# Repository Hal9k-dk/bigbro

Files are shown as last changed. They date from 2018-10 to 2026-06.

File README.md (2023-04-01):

# BigBro

BigBro is the system used by Hal9K to control access to its different advanced
machines, with RFID based access control.

The system is designed to cut power to the machines if no valid key-card is present
or in the special case of a 3D printer, if no special key-card is present, 
and a print isn't ongoing.

The first version of BigBro was designed around the ESP8266, specifically the WEMOS D1 mini.
Version 2 uses ESP32 with the [EspressIf ESP-IDF](https://idf.espressif.com/).

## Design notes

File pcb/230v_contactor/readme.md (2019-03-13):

# Contactor PCB
PCB design for the normal big-bro access boxes, meant to control a 230v contactor.

Eagle version 7.2.0

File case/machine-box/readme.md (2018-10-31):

## Case for the power-monitoring PCB

The source files for the case are [here](https://cad.onshape.com/documents/f34608c3b50537d27d2a70f4/w/dc4bf4f182cd748e33a69883/e/08b9ab1bdb92c4a2750b073b).

It's made on OnShape. To do anything but view you'll need a free account. For that reason step and stl files for the case have been provided here as well, in a folder of their own.

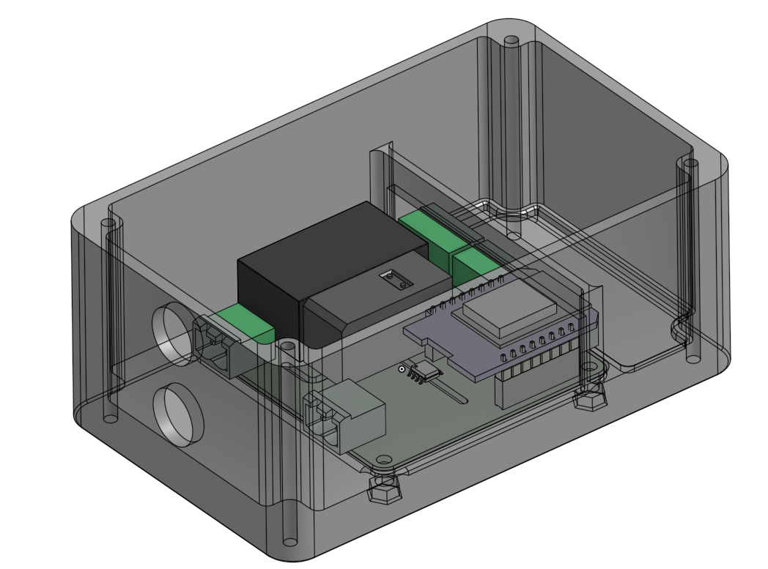
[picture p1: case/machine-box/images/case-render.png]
Case Render


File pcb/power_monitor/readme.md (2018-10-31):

# Power monitoring acces system

A module based on AndersV209s work on the Wemos D1 Mini based boards.
Main changes are:

- DPST relay that breaks both Live and Neutral and handles 8A
- ACS723 10A current monitoring chip

The changes have been done to support use on 3D printers, or other machines where the user won't be expected to leave their key FOB in the device, and where the board can then determine end of use when power draw drops significantly 

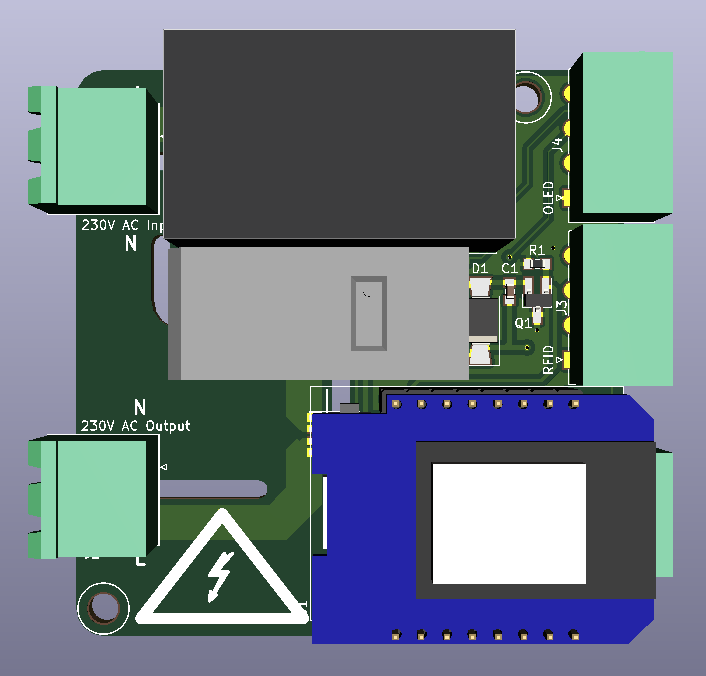
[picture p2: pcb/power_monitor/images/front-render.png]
Front-Render

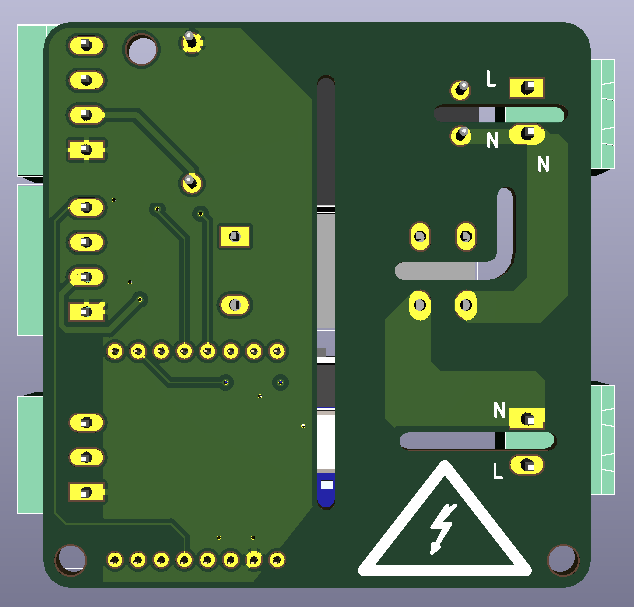
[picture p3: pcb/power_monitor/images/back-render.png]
Back-Render


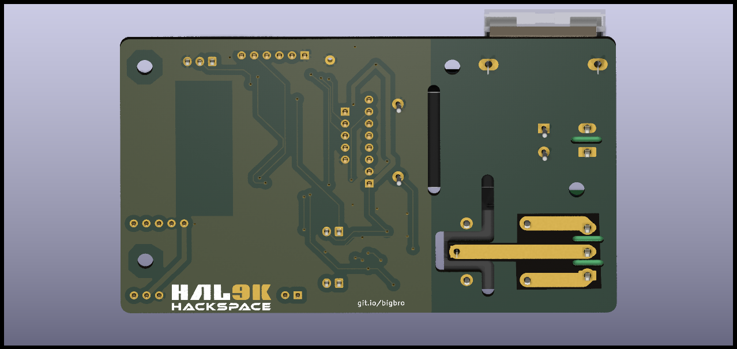
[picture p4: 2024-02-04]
pcb/bigbro_box_back.png

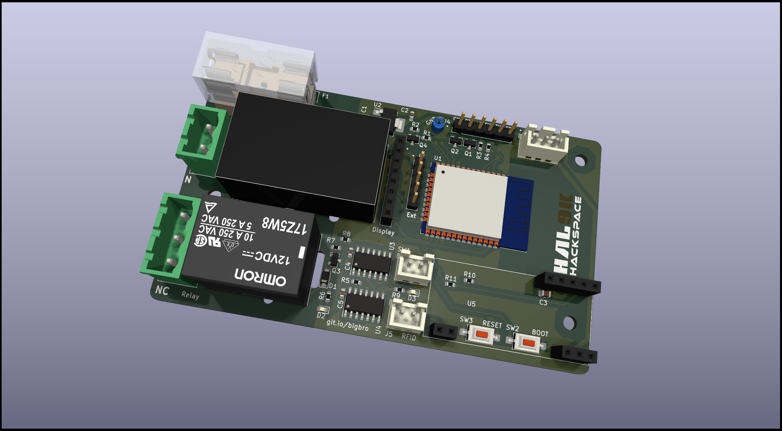
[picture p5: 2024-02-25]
pcb/bigbro_box.png

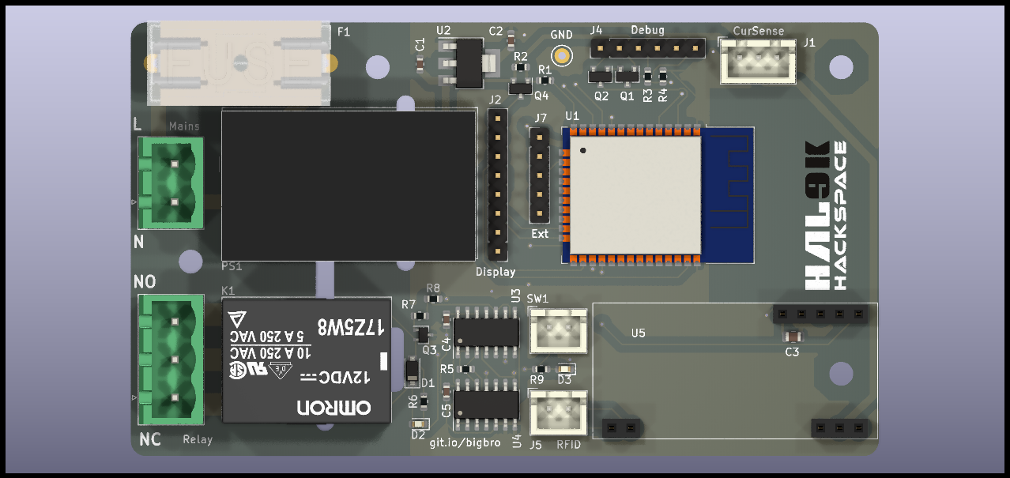
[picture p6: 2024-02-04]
pcb/bigbro_box_front.png

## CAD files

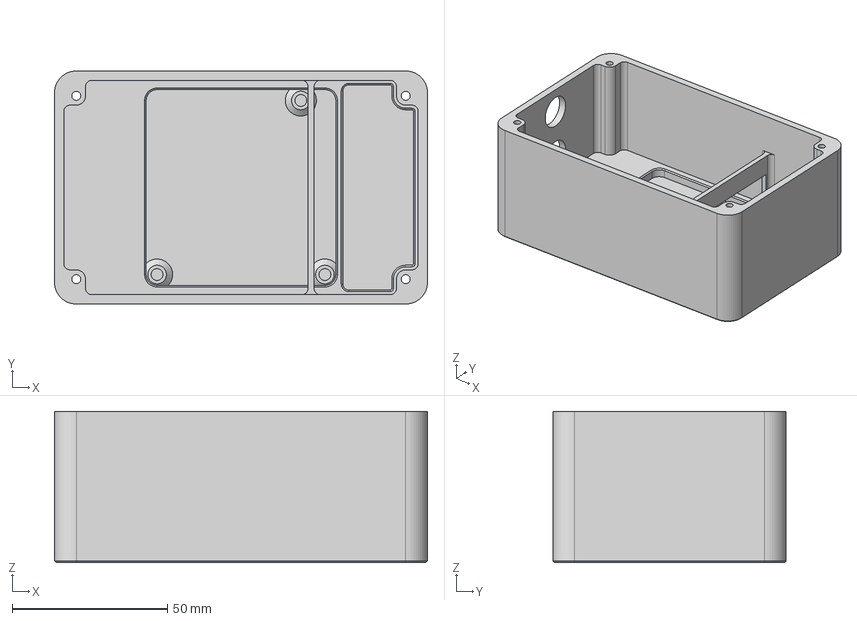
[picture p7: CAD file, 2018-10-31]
case/machine-box/step/Power monitor - Case.step
120.0 x 75.0 x 48.6 mm

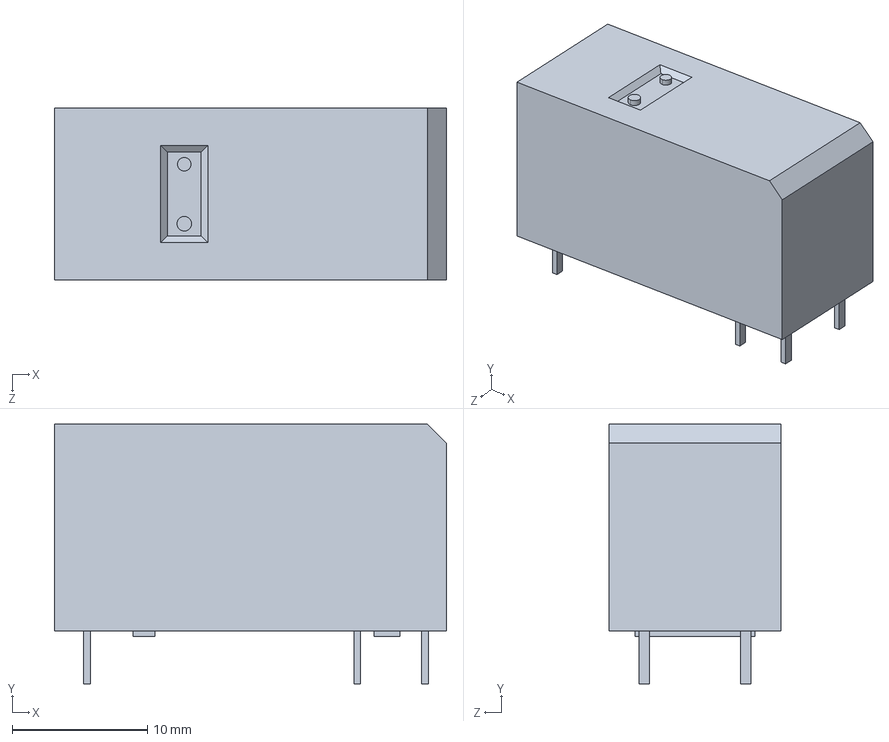
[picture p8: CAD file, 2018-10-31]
pcb/power_monitor/3Dmodels/G2RL_2A.step
29.0 x 19.2 x 12.7 mm

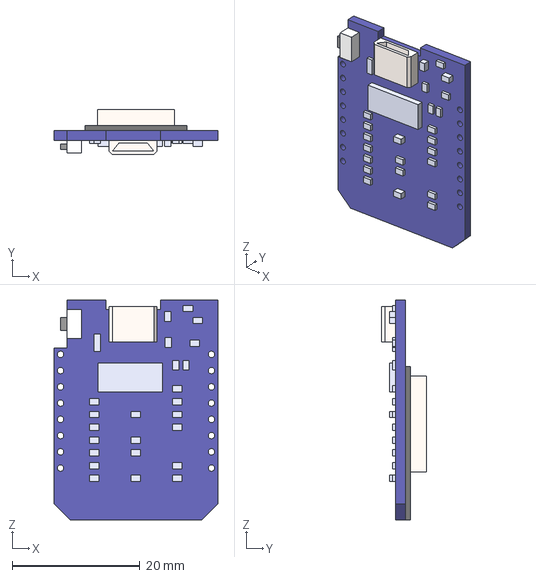
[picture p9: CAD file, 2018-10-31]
pcb/power_monitor/3Dmodels/WEMOSD1mini.step
25.6 x 7.00 x 34.4 mm

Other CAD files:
case/machine-box/stl/Power monitor - Case.stl

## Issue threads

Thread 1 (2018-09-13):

Class based branch(platformio) doesn't read softwareSerial

Duckle29, 2018-09-13:
For some odd reason, the software serial input from the RFID read always reads 0.

jenrik, 2018-09-14:
Both led in BaseController and the cardreader softwareserial uses pin 14

Duckle29, 2018-09-14:
Changed pin definition. The LED now works, so that's nice. This issue sadly isn't solved though :(

Duckle29, 2018-09-15:
Check bughunt branch to see the code

For some reason, interrupts don't fire in software serial, if the controller is of type ACS, derived from class base

Duckle29, 2018-09-16:
This is what the issue looks like in the bughunt branch
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

The problem is different here. In this case it's no interrupts at all. I have verified that the "attachInterrupt" function is called in softwareserial, so it does try to attach an interrupt, but it doesn't take effect.

jenrik, 2018-09-20:
I have tried adding a counter to SoftwareSerial that gets incremented in SoftwareSerial::rxRead(). It's getting incremented a lot which seems to indicate that interrupts are triggered. The problem now seem to be that interrupts are triggered all the time regardless of whether the rx pin has changed state, and that the it always receives 0 on the software serial.

Closed 2018-09-22.

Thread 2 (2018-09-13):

Class based branch (platformIO) doesn't update OLED after boot-up

Duckle29, 2018-09-13:
It seems the OLED fails to update once the device is past its setup.

Duckle29, 2018-09-13:
In general, it just looks like shit stops working once we enter loop() Stuff that does work is:

- Anything serial menu related

Duckle29, 2018-09-17:
This doesn't seem to actually be a thing

Closed 2018-09-17.

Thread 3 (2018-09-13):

ESP hangs on software reboot

Duckle29, 2018-09-13:
Using Either ESP.reset() or ESP.restart() hangs the ESP, with periodic WDT resets, that still doesn't properly reset it.

However a power-cycle or a push of the reset button works as expected

larsch, 2018-09-19:
Perhaps: https://arduino-esp8266.readthedocs.io/en/2.4.2/faq/readme.html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

Duckle29, 2018-09-19:
Yep that's it

Closed 2018-09-19.

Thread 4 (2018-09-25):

OLED UI consistency

Duckle29, 2018-09-25:
The UI can currently be a bit messy, with current state appearing on different lines, and error messages causing empty lines with little info.

This needs to be reworked so that the user doesn't have any doubts about what's going on with the controller.

Additionally, we should consider removing the current readout, at least after initial testing of the box has been completed.

Duckle29, 2019-03-18:
Current readout removed, states on consistent lines. Errors should be shown

Suggestion was made to not show the machine name if we need a line for additional information, as the boxes are attached to the relevant machines

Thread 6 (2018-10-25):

Display shows last user who swiped their card, not the actual last user

bullestock, 2018-10-25:
Simply inserting a card erases any information about the last user who printed.

Probably better to get the info from the backend anyway,

Duckle29, 2018-10-27:
Is there an endpoint on the API to get the last user for the printer?

bullestock, 2018-10-27:
> Is there an endpoint on the API to get the last user for the printer?

But of course: https://github.com/bullestock/acs/blob/master/apidoc.md

Duckle29, 2019-03-14:
This has been implemented with EEPROM storage for now. Will open a new issue on moving this functionality server-side when I'm at a pc

Closed 2019-03-14.

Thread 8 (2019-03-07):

In case of watchdog resets, the box cycles power several times

Duckle29, 2019-03-07:
Suggested solution is to prevent the box from enabling the machine if a card is present at boot.

Duckle29, 2019-03-14:
Issue 8 has been merged into platformio. We suspect the PSUs are dieing after prolonged 24/7 on time

AndersV209, 2020-05-26:
the issue is not caused by a power issue, there have been added a hardware latch to keep machine unlocked even if the esp restarts

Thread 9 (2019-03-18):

Move "last user" memory to access server

Duckle29, 2019-03-18:
To continue what was started in [issue#6](https://github.com/Hal9k-dk/bigbro/issues/6)

Currently the last user to print is stored in EEPROM, and read back if a card isn't present, and the state is IDLE. We might want to move this functionality server side.

This issue is to discuss that.

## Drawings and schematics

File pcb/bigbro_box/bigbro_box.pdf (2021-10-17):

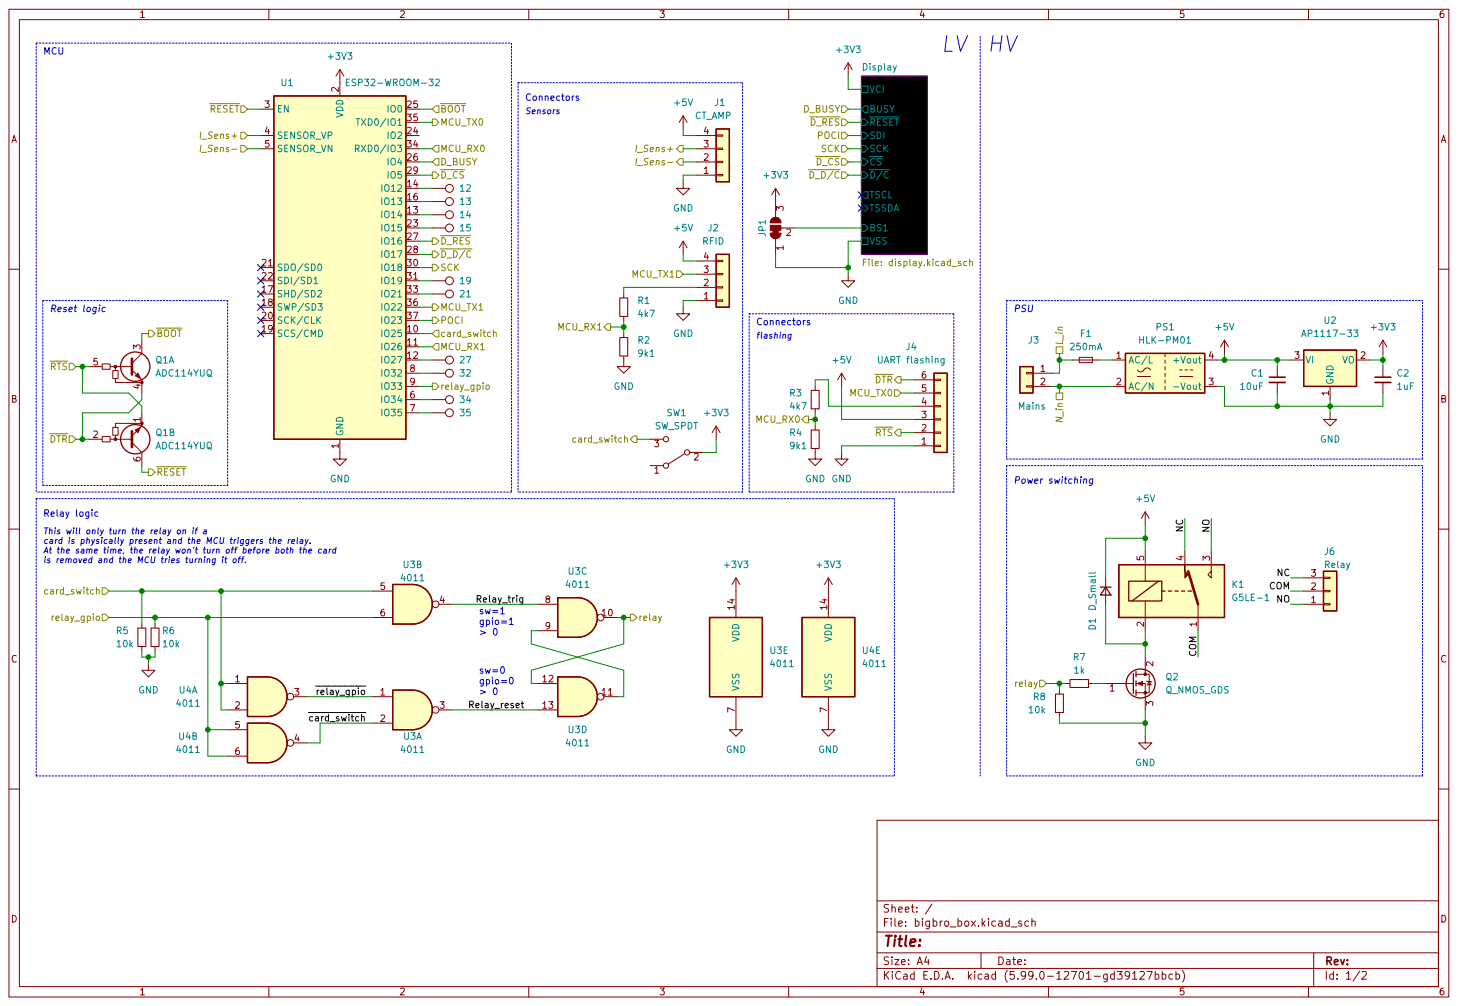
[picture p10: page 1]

TSCL BS1 VCI VSS Display

2 SCK/CLK 20 SDO/SD0 21 SDI/SD1 22

is removed and the MCU tries turning it off. Relay logic
This will only turn the relay on if a card is physically present and the MCU triggers the relay. At the same time, the relay won't turn off before both the card

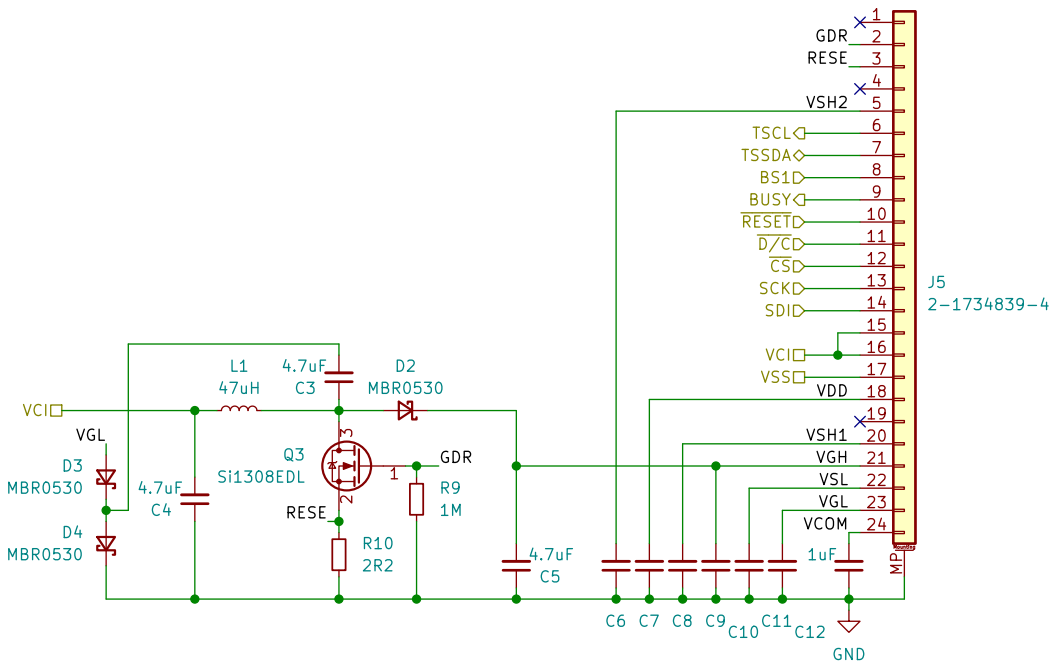
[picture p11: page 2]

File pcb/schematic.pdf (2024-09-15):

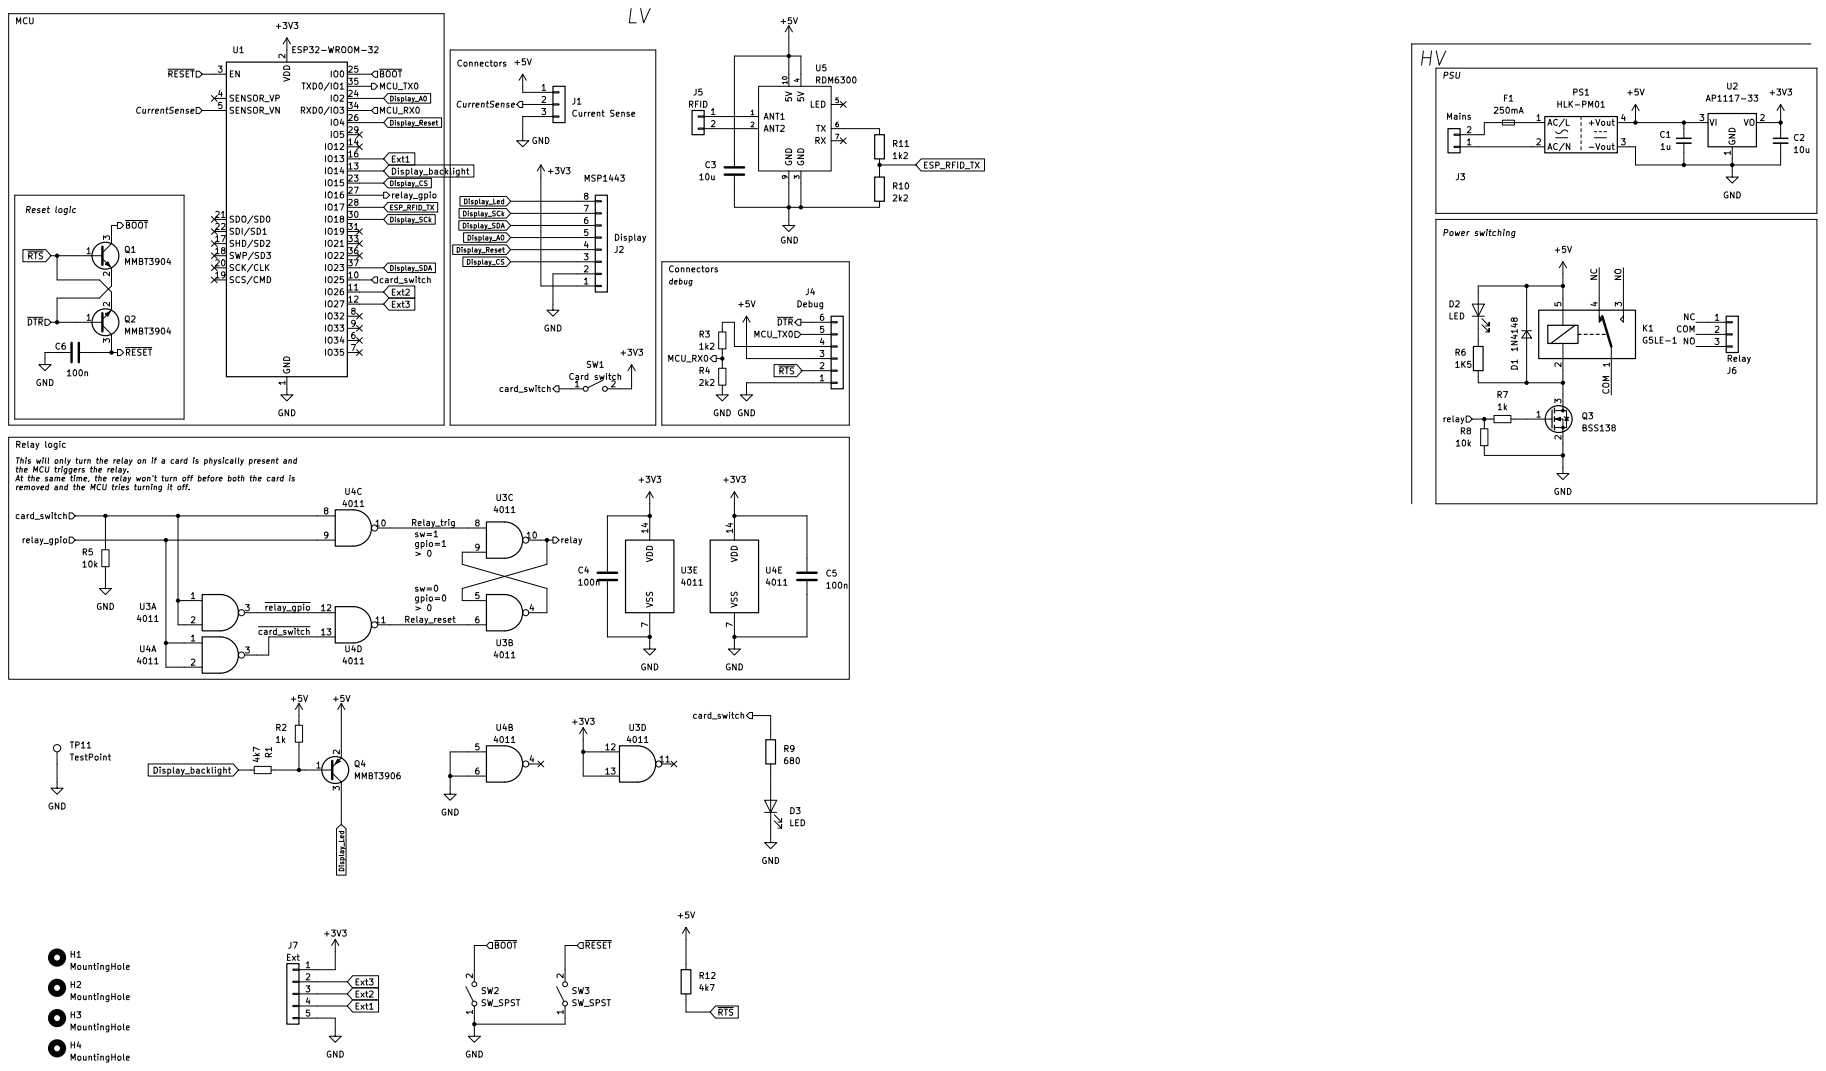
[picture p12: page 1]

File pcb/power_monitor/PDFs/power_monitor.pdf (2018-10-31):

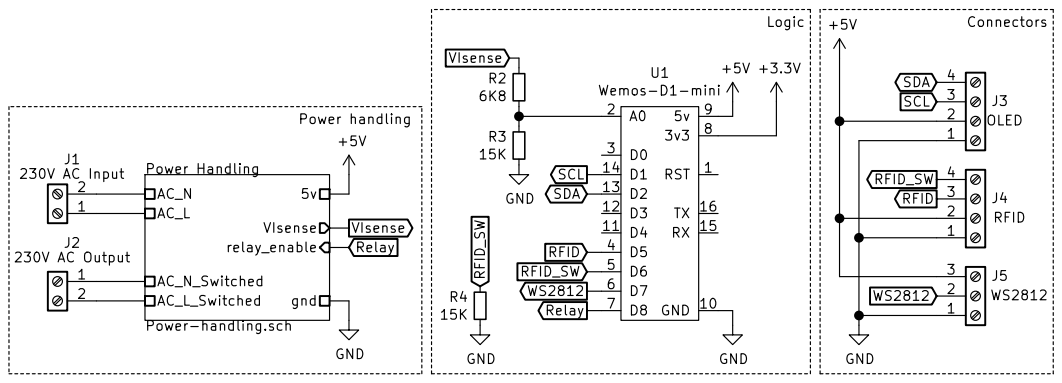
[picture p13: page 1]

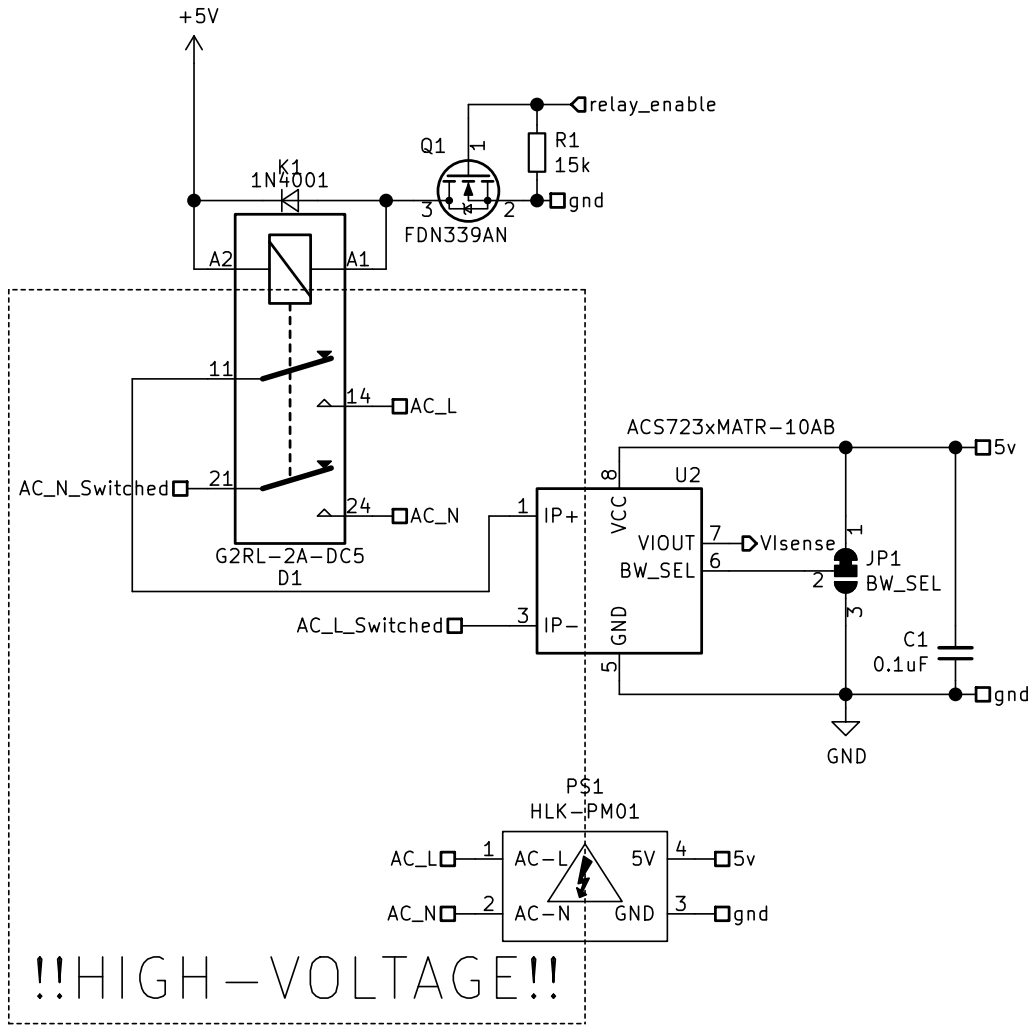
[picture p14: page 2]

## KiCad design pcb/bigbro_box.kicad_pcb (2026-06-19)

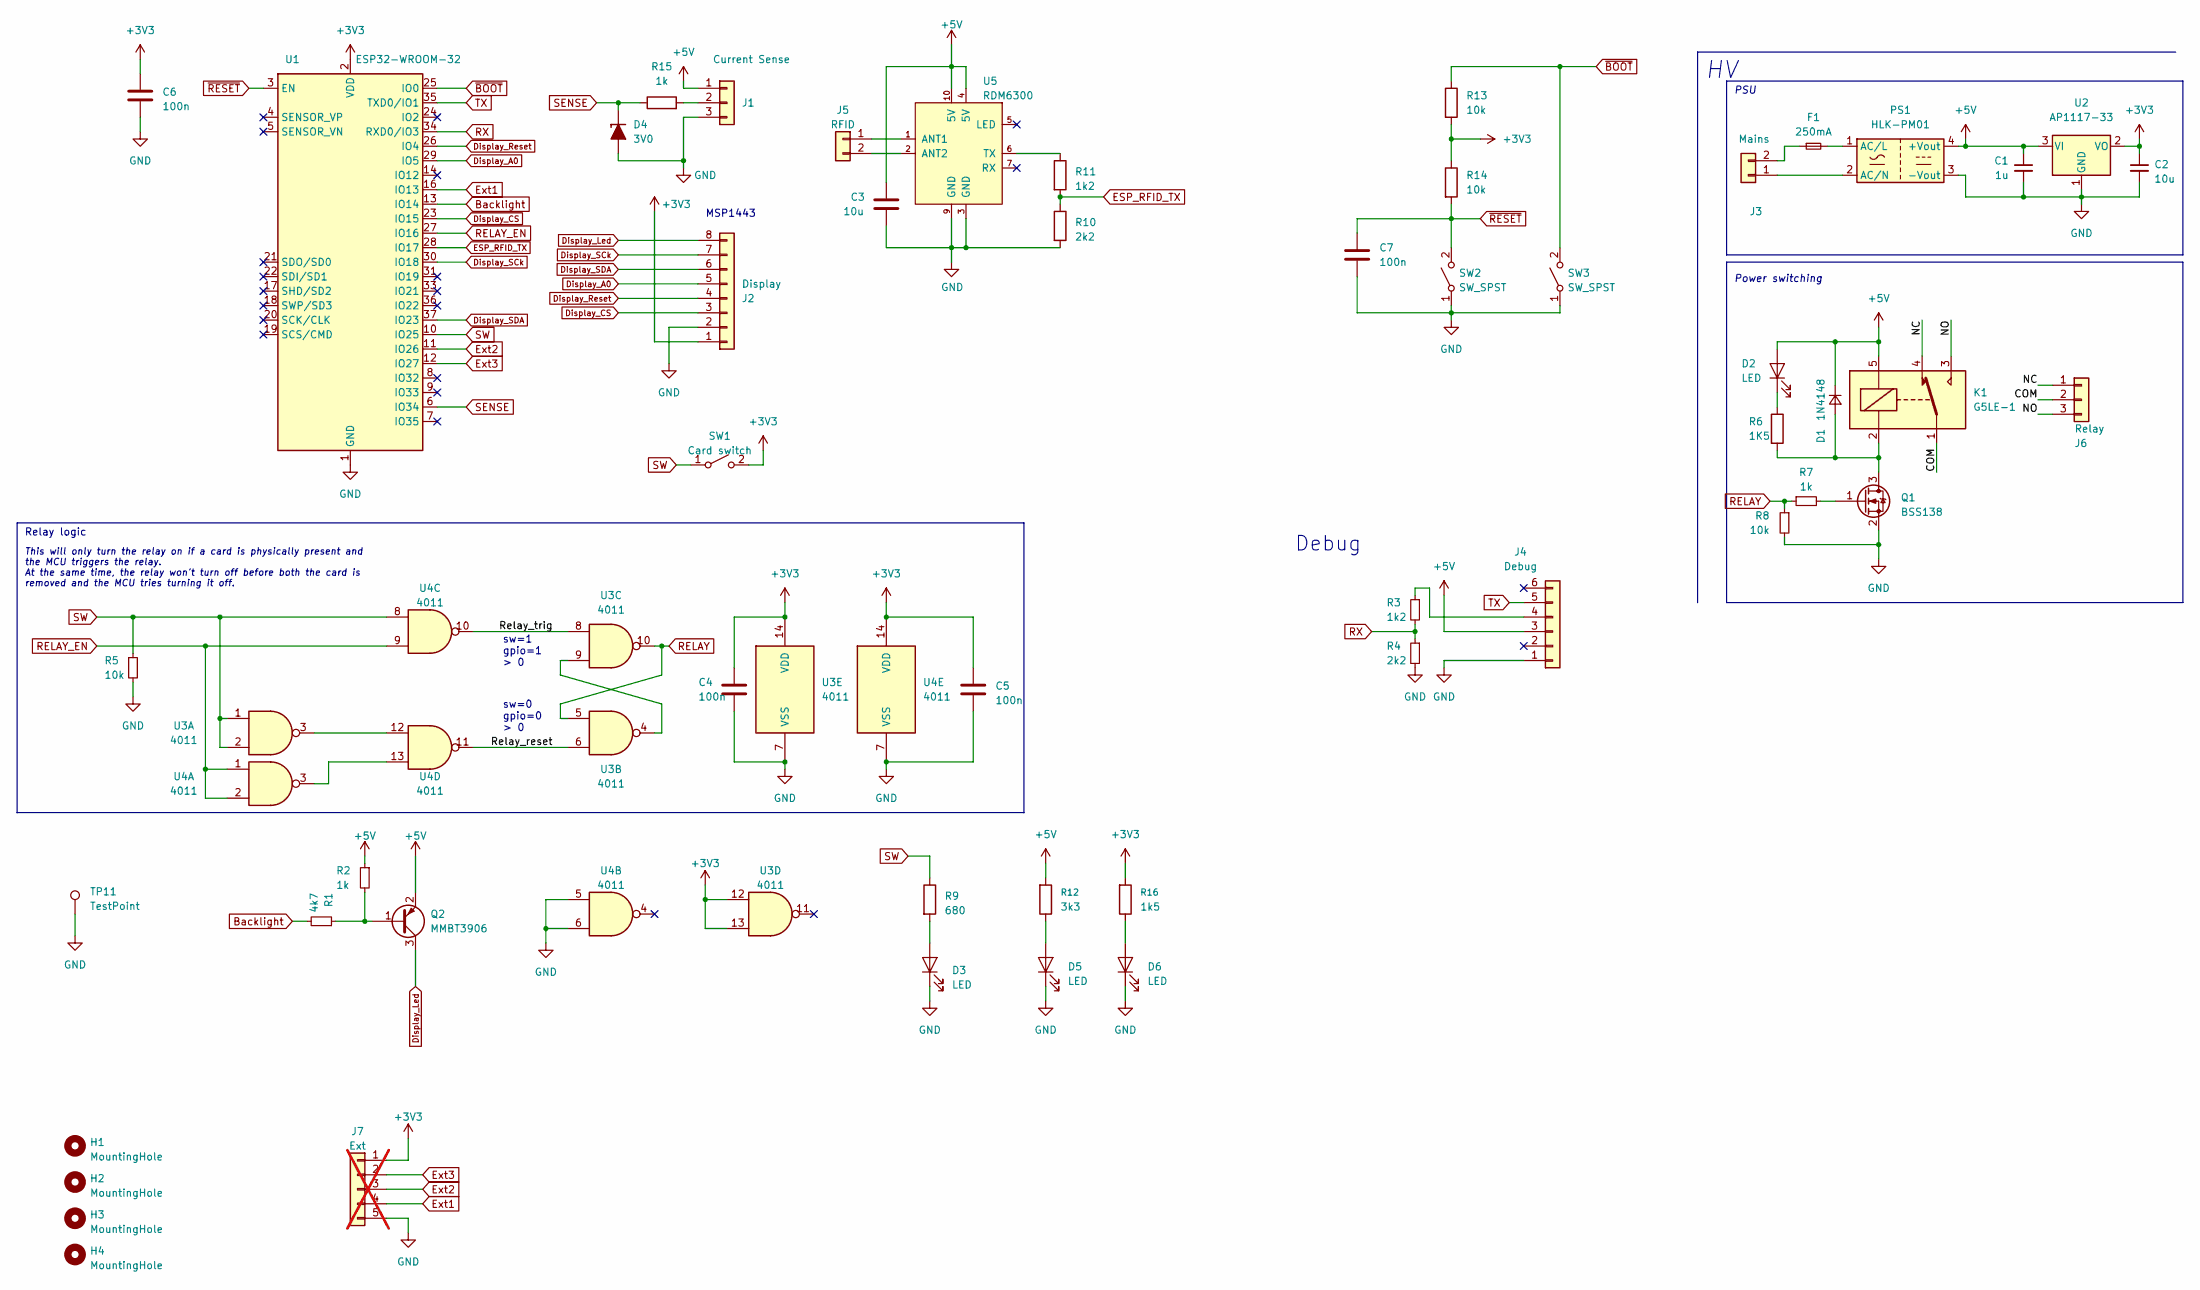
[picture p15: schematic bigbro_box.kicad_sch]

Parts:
C1: 1u; C_0603_1608Metric; LCSC C15849
C2: 10u; C_0603_1608Metric; LCSC C96446
C3: 10u; C_0603_1608Metric
C4, C5, C6: 100n; C_0603_1608Metric; LCSC C14663
C7: 100n; C_0603_1608Metric
D1: 1N4148; D_SOD-123
D2, D3, D5, D6: LED; LED_0603_1608Metric
D4: 3V0; D_MiniMELF
F1: 250mA; Fuse_Littelfuse_395Series
H1, H2, H3, H4: MountingHole; MountingHole_3.2mm_M3
J1: Current Sense; JST_XH_B3B-XH-A_1x03_P2.50mm_Vertical; LCSC C144394
J2: Display; PinSocket_1x08_P2.54mm_Vertical
J3: Mains; PhoenixContact_MSTBVA_2,5_2-G-5,08_1x02_P5.08mm_Vertical
J4: Debug; PinHeader_1x06_P2.54mm_Vertical; LCSC C37208
J5: RFID; JST_XH_B2B-XH-A_1x02_P2.50mm_Vertical
J6: Relay; PhoenixContact_MSTBVA_2,5_3-G-5,08_1x03_P5.08mm_Vertical
J7: Ext; PinHeader_1x05_P2.54mm_Vertical; not fitted
K1: G5LE-1; Relay_SPDT_Omron-G5LE-1
PS1: HLK-PM01; Converter_ACDC_HiLink_HLK-PMxx
Q1: BSS138; SOT-23
Q2: MMBT3906; SOT-23
R1: 4k7; R_0603_1608Metric; LCSC C23162
R2, R7: 1k; R_0603_1608Metric; LCSC C14676
R3: 1k2; R_0603_1608Metric; LCSC C22765
R4: 2k2; R_0603_1608Metric; LCSC C5362360
R5, R8: 10k; R_0603_1608Metric; LCSC C15401
R6: 1K5; R_0603_1608Metric; LCSC C22843
R9: 680; R_0603_1608Metric
R10: 2k2; R_0603_1608Metric
R11: 1k2; R_0603_1608Metric
R12: 3k3; R_0603_1608Metric
R13, R14: 10k; R_0603_1608Metric
R15: 1k; R_0603_1608Metric
R16: 1k5; R_0603_1608Metric
SW1: Card switch; JST_XH_B2B-XH-A_1x02_P2.50mm_Vertical
SW2, SW3: SW_SPST; SW_SPST_CK_RS282G05A3
TP11: TestPoint; TestPoint_Keystone_5000-5004_Miniature
U1: ESP32-WROOM-32; LCSC C95209
U2: AP1117-33; SOT-223-3_TabPin2
U3, U4: 4011; SOIC-14_3.9x8.7mm_P1.27mm
U5: RDM6300; RDM6300_B38.5x18.2mm

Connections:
+3V3: C2.1, C4.1, C5.1, C6.1, J2.1, J7.1, R13.2, R14.1, R16.1, SW1.2 (B), U1.2 (VDD), U2.2 (VO), U3.12, U3.13, U3.14 (VDD), U4.14 (VDD)
+5V: C1.1, C3.1, D1.1 (K), D2.2 (A), J1.1, J4.3, K1.5, PS1.4 (+Vout), Q2.2 (E), R2.1, R12.1, U2.3 (VI), U5.4 (5V), U5.10 (5V)
/COM: J6.2, K1.1
/NC: J6.1, K1.4
/NO: J6.3, K1.3
/Relay_reset: U3.6, U4.11
/Relay_trig: U3.8, U4.10
Backlight: R1.2, U1.13 (IO14)
Display_A0: J2.5, U1.29 (IO5)
Display_CS: J2.3, U1.23 (IO15)
Display_Led: J2.8, Q2.3 (C)
Display_Reset: J2.4, U1.26 (IO4)
Display_SCk: J2.7, U1.30 (IO18)
Display_SDA: J2.6, U1.37 (IO23)
ESP_RFID_TX: R10.1, R11.2, U1.28 (IO17)
Ext1: J7.4, U1.16 (IO13)
Ext2: J7.3, U1.11 (IO26)
Ext3: J7.2, U1.12 (IO27)
GND: C1.2, C2.2, C3.2, C4.2, C5.2, C6.2, C7.2, D3.1 (K), D4.2 (A), D5.1 (K), D6.1 (K), J1.3, J2.2, J4.1, J7.5, PS1.3 (-Vout), Q1.2 (S), R4.2, R5.2, R8.2, R10.2, SW2.1 (A), SW3.1 (A), TP11.1 (1_1), U1.1 (GND), U1.15 (GND), U1.38 (GND), U1.39 (GND), U2.1 (GND), U3.7 (VSS), U4.5, U4.6, U4.7 (VSS), U5.3 (GND), U5.9 (GND)
unnamed: D1.2 (A), K1.2, Q1.3 (D), R6.2
unnamed: D2.1 (K), R6.1
unnamed: D3.2 (A), R9.2
unnamed: D5.2 (A), R12.2
unnamed: D6.2 (A), R16.2
unnamed: J1.2, R15.2
unnamed: J3.1, PS1.2 (AC/N)
unnamed: F1.1, J3.2
unnamed: J4.4, R3.1
unnamed: J5.1, U5.1 (ANT1)
unnamed: J5.2, U5.2 (ANT2)
unnamed: F1.2, PS1.1 (AC/L)
unnamed: Q1.1 (G), R7.2
unnamed: Q2.1 (B), R1.1, R2.2
unnamed: U3.3, U4.12
unnamed: U3.4, U3.9
unnamed: U4.3, U4.13
unnamed: R11.1, U5.6 (TX)
RELAY: R7.1, R8.1, U3.5, U3.10
RELAY_EN: U1.27 (IO16), U4.1, U4.2, U4.9
RX: R3.2, R4.1, U1.34 (RXD0/IO3)
SENSE: D4.1 (K), R15.1, U1.6 (IO34)
SW: R5.1, R9.1, SW1.1 (A), U1.10 (IO25), U3.1, U3.2, U4.8
TX: J4.5, U1.35 (TXD0/IO1)
~BOOT: R13.1, SW3.2 (B), U1.25 (IO0)
~RESET: C7.1, R14.2, SW2.2 (B), U1.3 (EN)

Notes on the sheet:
Power switching
Relay logic
sw=1 gpio=1 > 0
This will only turn the relay on if a card is physically present and the MCU triggers the relay. At the same time, the relay won't turn off before both the card is removed and the MCU tries turning it off.
Debug
sw=0 gpio=0 > 0
MSP1443
PSU

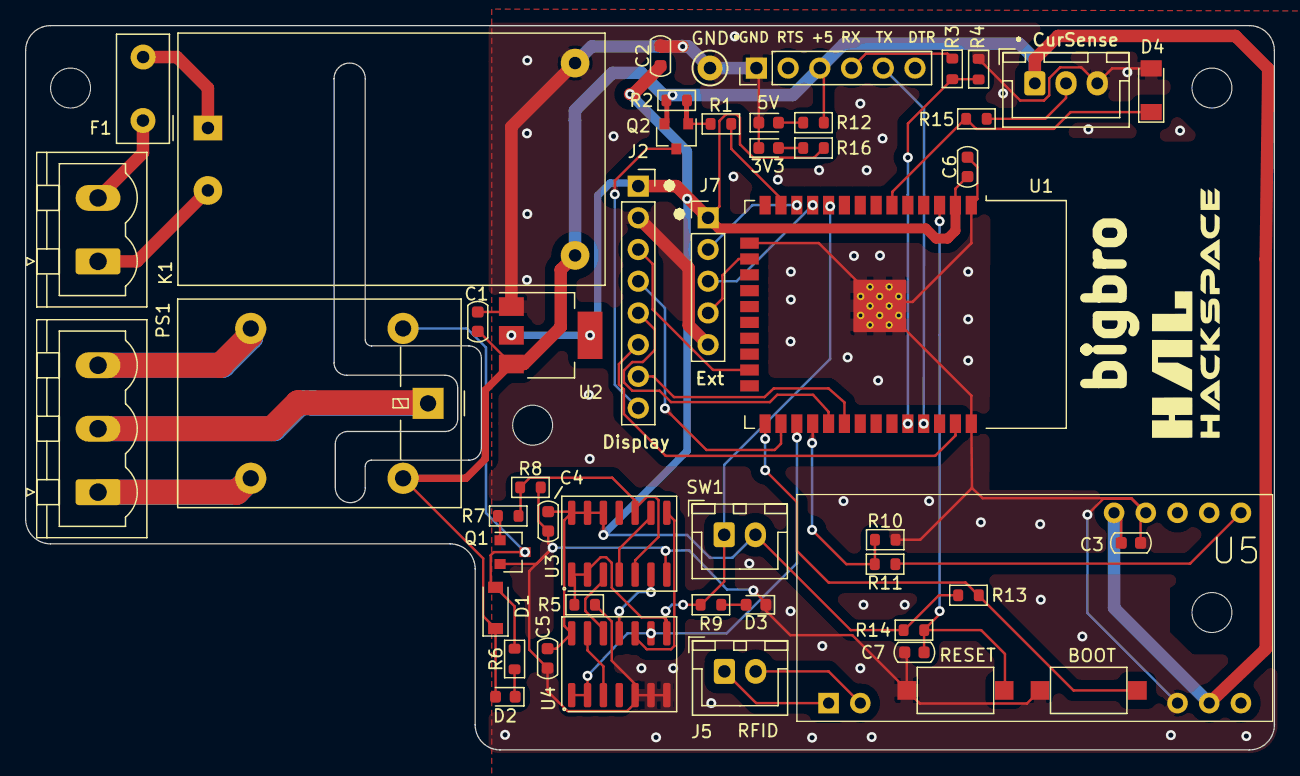
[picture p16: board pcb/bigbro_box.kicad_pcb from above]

Board: 2 copper layers, 100.0 x 58.0 mm, 54 parts (0 on the bottom side), 45 nets.

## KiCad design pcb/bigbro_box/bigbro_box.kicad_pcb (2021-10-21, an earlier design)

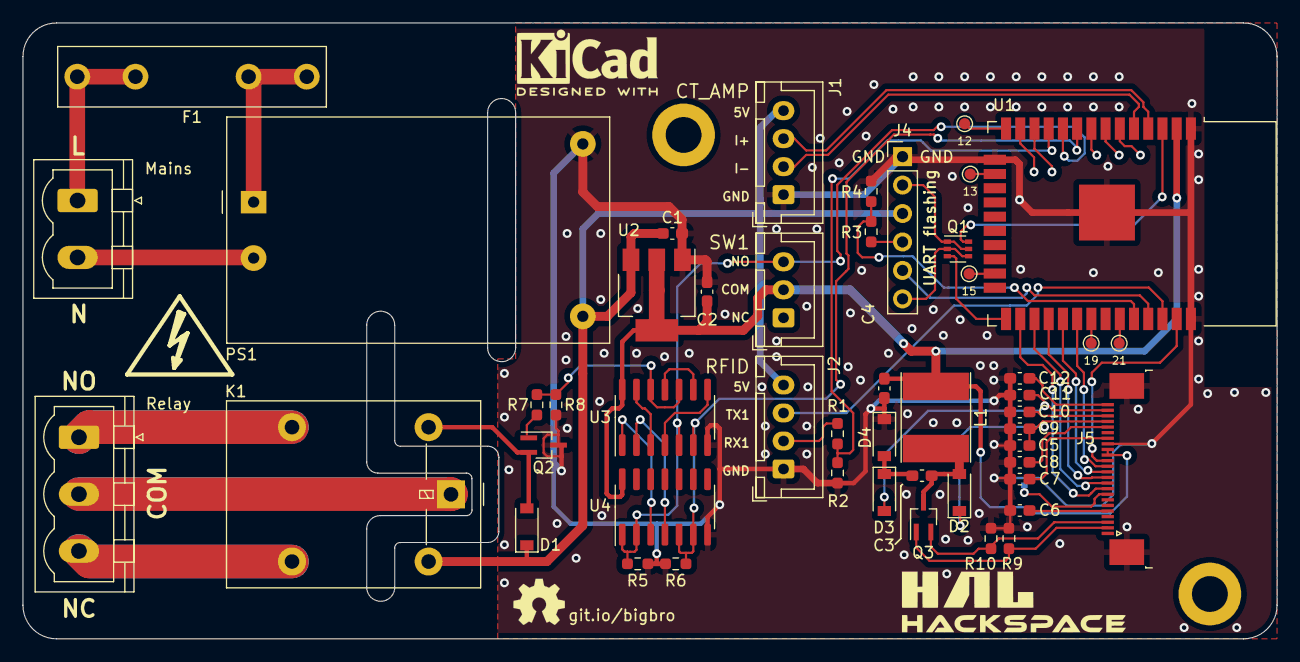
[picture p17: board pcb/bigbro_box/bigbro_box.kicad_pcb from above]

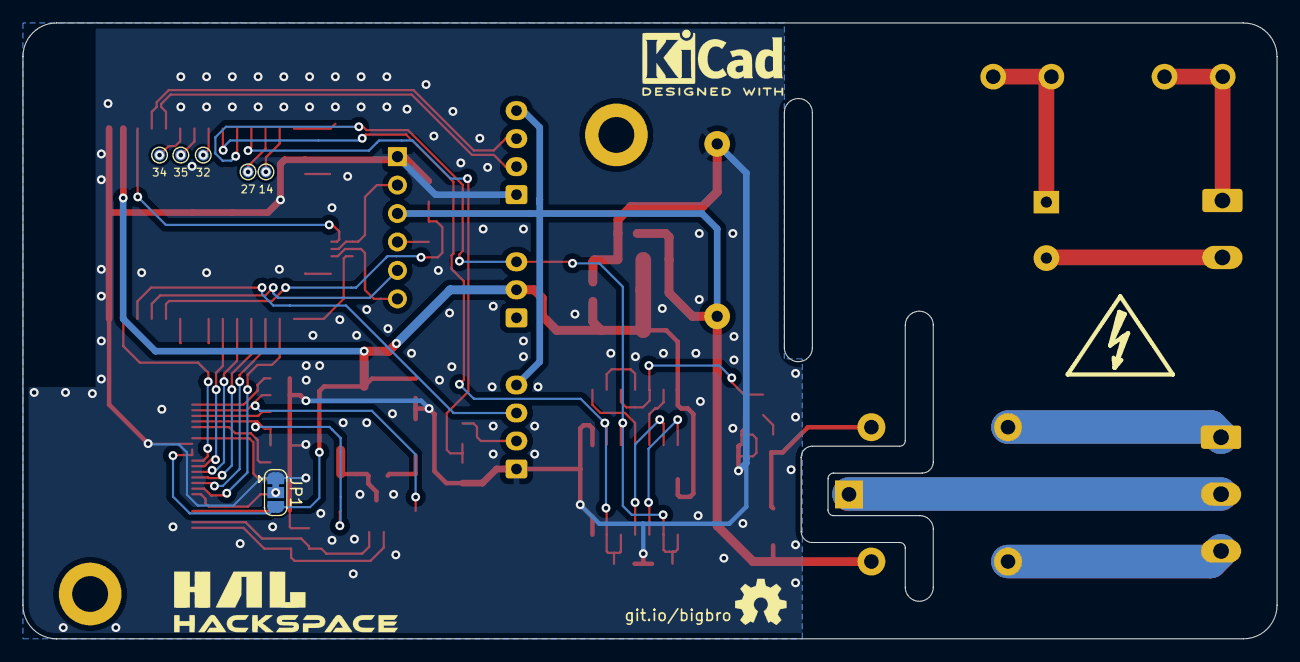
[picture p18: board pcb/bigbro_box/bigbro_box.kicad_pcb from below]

Board: 2 copper layers, 112.0 x 55.0 mm, 55 parts (6 on the bottom side), 59 nets.

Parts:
C1, C6, C7, C8, C9, C10, C11, C12: 1uF; C_0603_1608Metric_Pad1.08x0.95mm_HandSolder
C2: 10uF; C_0603_1608Metric_Pad1.08x0.95mm_HandSolder
C3, C4, C5: 4.7uF; C_0603_1608Metric_Pad1.08x0.95mm_HandSolder
D1: D_Small; D_SOD-123
D2, D3, D4: MBR0530; D_SOD-123
F1: 250mA; Fuseholder_Littelfuse_445_030_series_5x20mm
J1: CT_AMP; JST_XH_B4B-XH-A_1x04_P2.50mm_Vertical
J2: RFID; JST_XH_B4B-XH-A_1x04_P2.50mm_Vertical
J3: Mains; PhoenixContact_MSTBVA_2,5_2-G-5,08_1x02_P5.08mm_Vertical
J4: UART flashing; PinHeader_1x06_P2.54mm_Vertical
J5: 2-1734839-4; TE_2-1734839-4_1x24-1MP_P0.5mm_Horizontal
J6: Relay; PhoenixContact_MSTBVA_2,5_3-G-5,08_1x03_P5.08mm_Vertical
JP1: D_BS; SolderJumper-3_P1.3mm_Bridged12_RoundedPad1.0x1.5mm
K1: G5LE-1; Relay_SPDT_Omron-G5LE-1
L1: 47uH; L_Taiyo-Yuden_NR-60xx_HandSoldering
PS1: HLK-PM01; Converter_ACDC_HiLink_HLK-PMxx
Q1: ADC114YUQ; SOT-363_SC-70-6
Q2: Q_NMOS_GDS; SOT-323_SC-70_Handsoldering
Q3: Si1308EDL; SOT-323_SC-70_Handsoldering
R1, R3: 1k2; R_0603_1608Metric_Pad0.98x0.95mm_HandSolder
R2, R4: 2k2; R_0603_1608Metric_Pad0.98x0.95mm_HandSolder
R5, R6, R8: 10k; R_0603_1608Metric_Pad0.98x0.95mm_HandSolder
R7: 1k; R_0603_1608Metric_Pad0.98x0.95mm_HandSolder
R9: 1M; R_0603_1608Metric_Pad0.98x0.95mm_HandSolder
R10: 2R2; R_0603_1608Metric_Pad0.98x0.95mm_HandSolder
SW1: SW_SPDT; JST_XH_B3B-XH-A_1x03_P2.50mm_Vertical
TP1: 12; TestPoint_Pad_D1.0mm
TP2: 13; TestPoint_Pad_D1.0mm
TP3: 14; TestPoint_Pad_D1.0mm
TP4: 15; TestPoint_Pad_D1.0mm
TP5: 19; TestPoint_Pad_D1.0mm
TP6: 21; TestPoint_Pad_D1.0mm
TP7: 27; TestPoint_Pad_D1.0mm
TP8: 32; TestPoint_Pad_D1.0mm
TP9: 34; TestPoint_Pad_D1.0mm
TP10: 35; TestPoint_Pad_D1.0mm
U1: ESP32-WROOM-32
U2: AP1117-33; SOT-223-3_TabPin2
U3, U4: 4011; SOIC-14_3.9x8.7mm_P1.27mm

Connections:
+3V3: C2.1, C4.2, J5.15, J5.16, JP1.3 (B), L1.1, SW1.2 (B), U1.2 (VDD), U2.2 (VO), U3.14 (VDD), U4.14 (VDD)
+5V: C1.1, D1.1 (K), J1.4, J2.4, J4.3, K1.5, PS1.4 (+Vout), U2.3 (VI)
/COM: J6.2, K1.1
/D_BUSY: J5.9, U1.26 (IO4)
/Display/BS1: J5.8, JP1.2 (C)
/Display/GDR: J5.2, Q3.1 (G), R9.1
/Display/RESE: J5.3, Q3.2 (S), R10.1
/Display/VCOM: C12.2, J5.24
/Display/VDD: C7.2, J5.18
/Display/VGH: C5.2, C9.2, D2.1 (K), J5.21
/Display/VGL: C11.2, D3.2 (A), J5.23
/Display/VSH1: C8.2, J5.20
/Display/VSH2: C6.2, J5.5
/Display/VSL: C10.2, J5.22
/I_Sens+: J1.3, U1.4 (SENSOR_VP)
/I_Sens-: J1.2, U1.5 (SENSOR_VN)
/L_in: F1.1, J3.1
/MCU_RX0: R3.2, R4.1, U1.34 (RXD0/IO3)
/MCU_RX1: R1.2, R2.1, U1.11 (IO26)
/MCU_TX0: J4.5, U1.35 (TXD0/IO1)
/MCU_TX1: J2.3, U1.36 (IO22)
/NC: J6.3, K1.4
/NO: J6.1, K1.3
/N_in: J3.2, PS1.2 (AC/N)
/POCI: J5.14, U1.37 (IO23)
/Relay_reset: U3.3, U3.13
/Relay_trig: U3.4, U3.8
/SCK: J5.13, U1.30 (IO18)
/card_switch: R5.1, SW1.3 (C), U1.10 (IO25), U3.5, U4.1, U4.2
/relay: R7.1, R8.1, U3.10, U3.12
/relay_gpio: R6.1, U1.9 (IO33), U3.6, U4.5, U4.6
/~BOOT: Q1.3 (C1), U1.25 (IO0)
/~DTR: J4.6, Q1.2 (B2), Q1.4 (E1)
/~D_CS: J5.12, U1.29 (IO5)
/~D_D/C: J5.11, U1.28 (IO17)
/~D_RES: J5.10, U1.27 (IO16)
/~RESET: Q1.6 (C2), U1.3 (EN)
/~RTS: J4.2, Q1.1 (E2), Q1.5 (B1)
/~card_switch: U3.2, U4.4
/~relay_gpio: U3.1, U4.3
GND: C1.2, C2.2, C4.1, C5.1, C6.1, C7.1, C8.1, C9.1, C10.1, C11.1, C12.1, D4.1 (K), J1.1, J2.1, J4.1, J5.17, J5.MP (MountPin), JP1.1 (A), PS1.3 (-Vout), Q2.3 (S), R2.2, R4.2, R5.2, R6.2, R8.2, R9.2, R10.2, U1.1 (GND), U1.15 (GND), U1.38 (GND), U1.39 (GND), U2.1 (GND), U3.7 (VSS), U4.7 (VSS)
unnamed: C3.1, D2.2 (A), L1.2, Q3.3 (D)
unnamed: C3.2, D3.1 (K), D4.2 (A)
unnamed: D1.2 (A), K1.2, Q2.2 (D)
unnamed: F1.2, PS1.1 (AC/L)
unnamed: J2.2, R1.1
unnamed: J4.4, R3.1
unnamed: Q2.1 (G), R7.2
unnamed: TP1.1, U1.14 (IO12)
unnamed: TP2.1, U1.16 (IO13)
unnamed: TP3.1, U1.13 (IO14)
unnamed: TP4.1, U1.23 (IO15)
unnamed: TP5.1, U1.31 (IO19)
unnamed: TP6.1, U1.33 (IO21)
unnamed: TP7.1, U1.12 (IO27)
unnamed: TP8.1, U1.8 (IO32)
unnamed: TP9.1, U1.6 (IO34)
unnamed: TP10.1, U1.7 (IO35)
unnamed: U3.9, U3.11

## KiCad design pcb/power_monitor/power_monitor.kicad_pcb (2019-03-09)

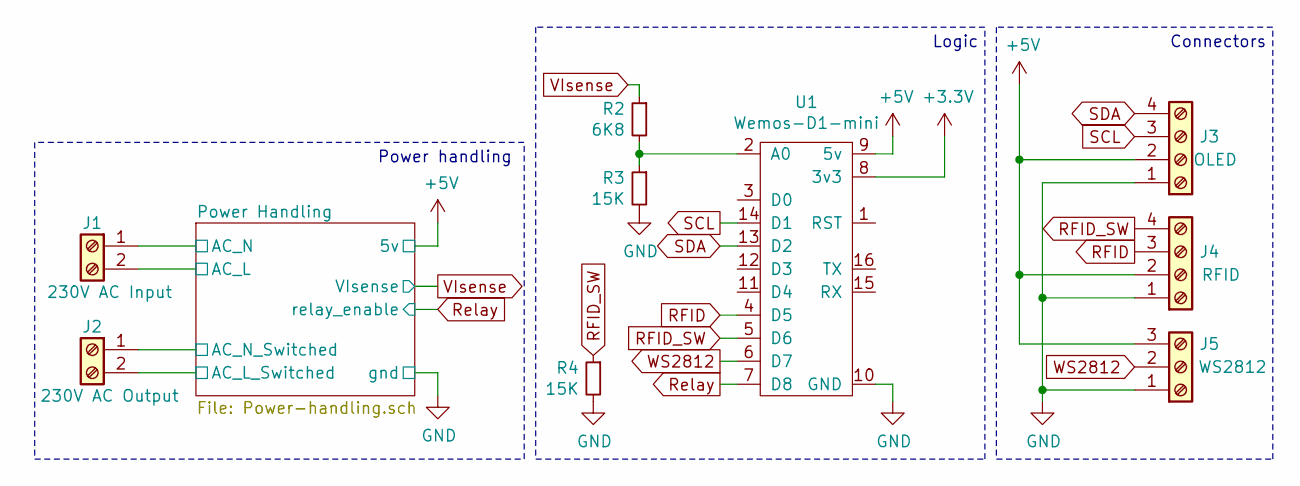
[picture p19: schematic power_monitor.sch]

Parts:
J1: 230V AC Input; PhoenixContact_MSTBA_2,5_2-G_1x02_P5.00mm_Horizontal
J2: 230V AC Output; PhoenixContact_MSTBA_2,5_2-G_1x02_P5.00mm_Horizontal
J3: OLED; PhoenixContact_MC_1,5_4-G-3.81_1x04_P3.81mm_Horizontal
J4: RFID; PhoenixContact_MC_1,5_4-G-3.81_1x04_P3.81mm_Horizontal
J5: WS2812; PhoenixContact_MC_1,5_3-G-3.81_1x03_P3.81mm_Horizontal
R2: 6K8; R_0603_1608Metric_Pad1.05x0.95mm_HandSolder
R3, R4: 15K; R_0603_1608Metric_Pad1.05x0.95mm_HandSolder
U1: Wemos-D1-mini; Wemos D1 Mini

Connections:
+5V: J3.2, J4.2, J5.3, U1.9 (5v); also elsewhere on the board
/Power Handling/AC_L: J1.2; also elsewhere on the board
/Power Handling/AC_L_Switched: J2.2; also elsewhere on the board
/Power Handling/AC_N: J1.1; also elsewhere on the board
/Power Handling/AC_N_Switched: J2.1; also elsewhere on the board
GND: J3.1, J4.1, J5.1, R3.2, R4.2, U1.10 (GND); also elsewhere on the board
unnamed: R2.2, R3.1, U1.2 (A0)
RFID: J4.3, U1.4 (D5)
RFID_SW: J4.4, R4.1, U1.5 (D6)
Relay: U1.7 (D8); also elsewhere on the board
SCL: J3.3, U1.14 (D1)
SDA: J3.4, U1.13 (D2)
VIsense: R2.1; also elsewhere on the board
WS2812: J5.2, U1.6 (D7)

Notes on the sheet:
Connectors
Logic
Power handling

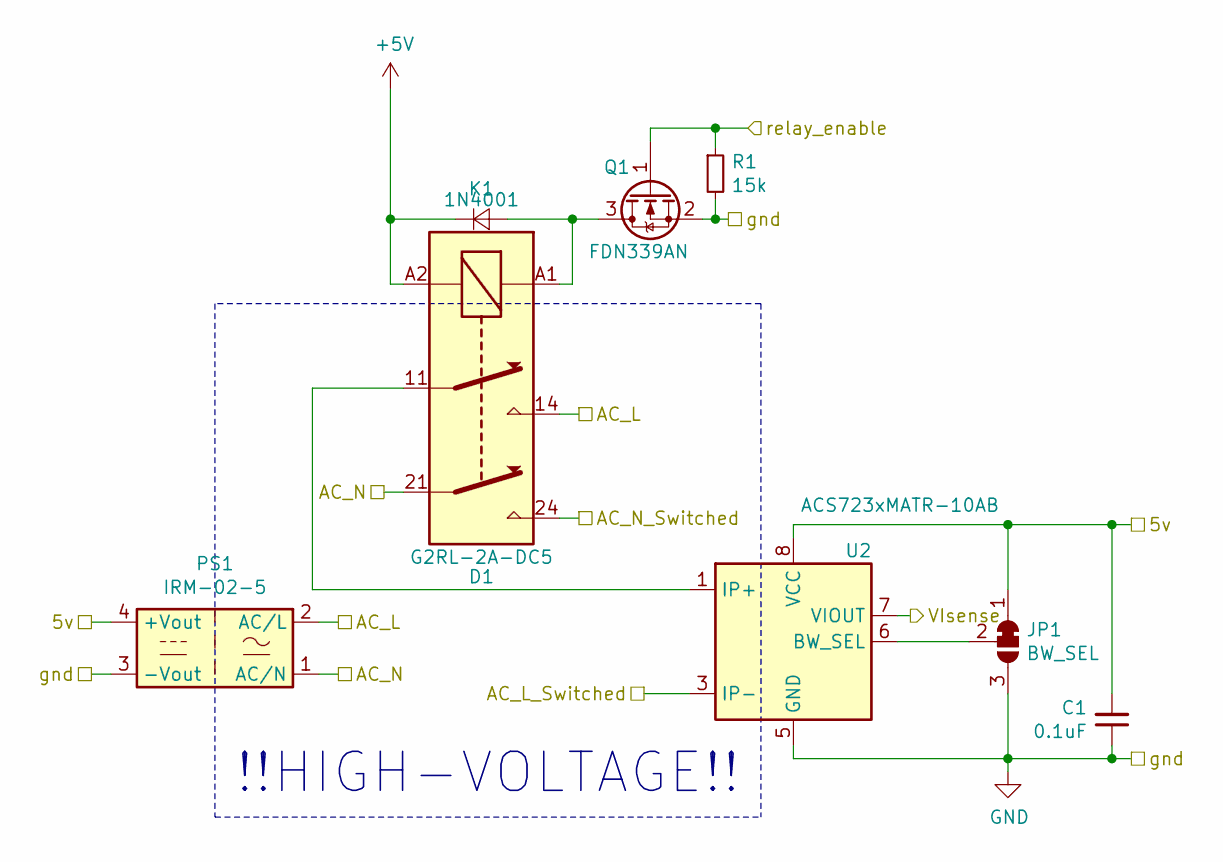
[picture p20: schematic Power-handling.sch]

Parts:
C1: 0.1uF; C_0603_1608Metric_Pad1.05x0.95mm_HandSolder
D1: 1N4001; D_SMA_Handsoldering
JP1: BW_SEL; SolderJumper-3_P1.3mm_Bridged2Bar12_RoundedPad1.0x1.5mm_Num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
K1: G2RL-2A-DC5; Relay_DPST_Schrack-RT2-FormA_RM5mm
PS1: IRM-02-5; Converter_ACDC_MeanWell_IRM-02-xx_THT
Q1: FDN339AN; SOT-23_Handsoldering
R1: 15k; R_0603_1608Metric_Pad1.05x0.95mm_HandSolder
U2: ACS723xMATR-10AB; SOIC-8_3.9x4.9mm_P1.27mm

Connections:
+5V: C1.2, D1.1 (K), JP1.1 (A), K1.A2, PS1.4 (+Vout), U2.8 (VCC); also elsewhere on the board
/Power Handling/AC_L: K1.14, PS1.2 (AC/L); also elsewhere on the board
/Power Handling/AC_L_Switched: U2.3 (IP-), U2.4 (IP-); also elsewhere on the board
/Power Handling/AC_N: K1.21, PS1.1 (AC/N); also elsewhere on the board
/Power Handling/AC_N_Switched: K1.24; also elsewhere on the board
GND: C1.1, JP1.3 (B), PS1.3 (-Vout), Q1.2 (S), R1.2, U2.5 (GND); also elsewhere on the board
unnamed: D1.2 (A), K1.A1, Q1.3 (D)
unnamed: JP1.2 (C), U2.6 (BW_SEL)
unnamed: K1.11, U2.1 (IP+), U2.2 (IP+)
Relay: Q1.1 (G), R1.1; also elsewhere on the board
VIsense: U2.7 (VIOUT); also elsewhere on the board

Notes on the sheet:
!!HIGH-VOLTAGE!!

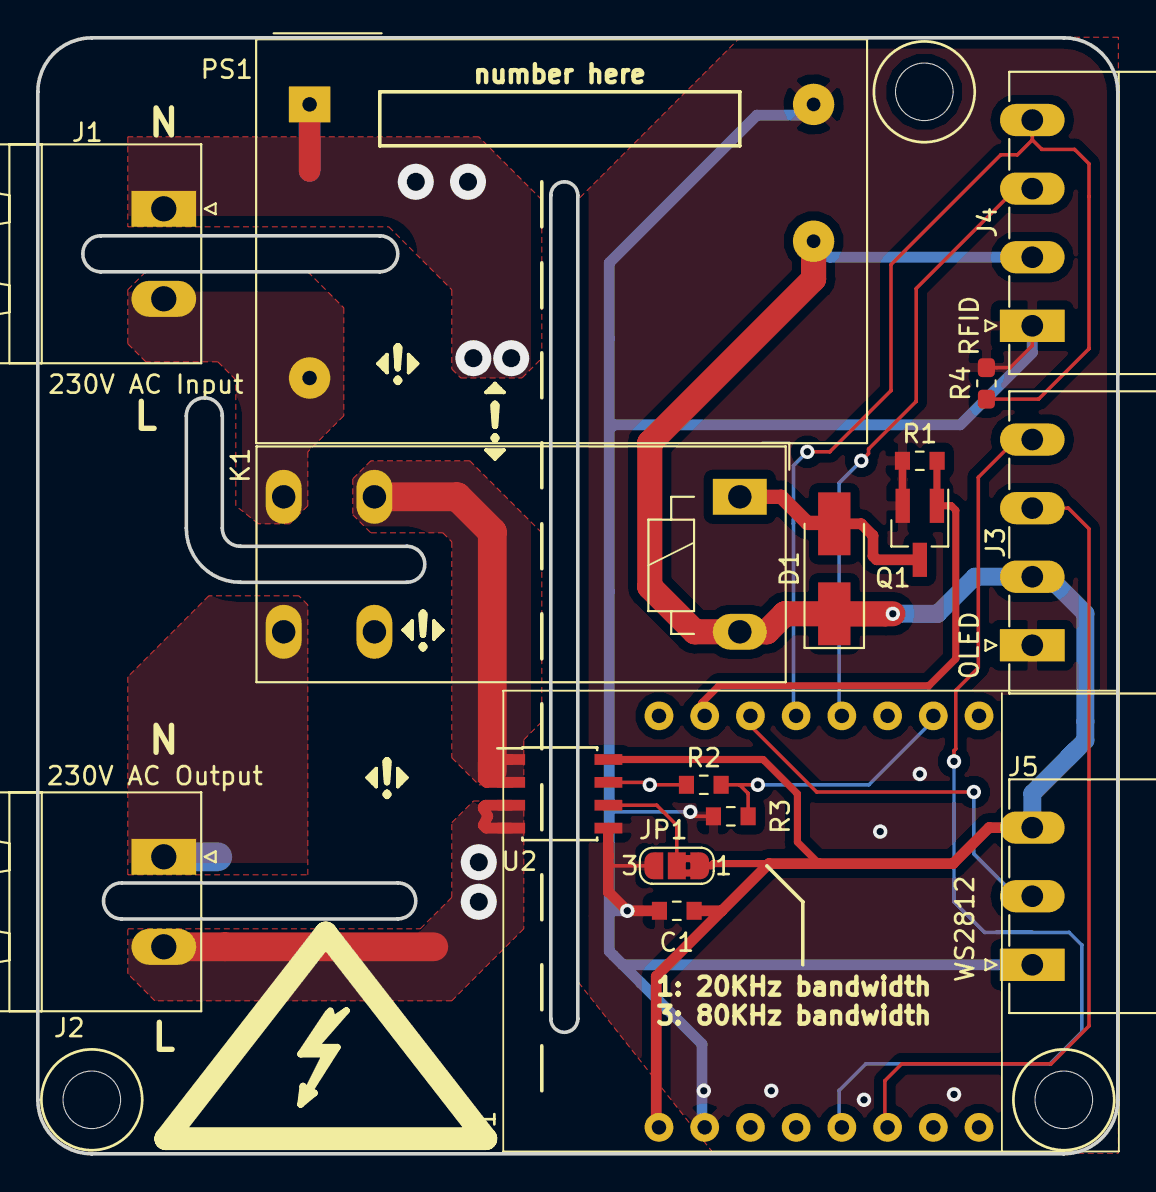
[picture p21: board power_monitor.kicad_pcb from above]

Board: 2 copper layers, 60.0 x 62.0 mm, 17 parts (0 on the bottom side), 17 nets.

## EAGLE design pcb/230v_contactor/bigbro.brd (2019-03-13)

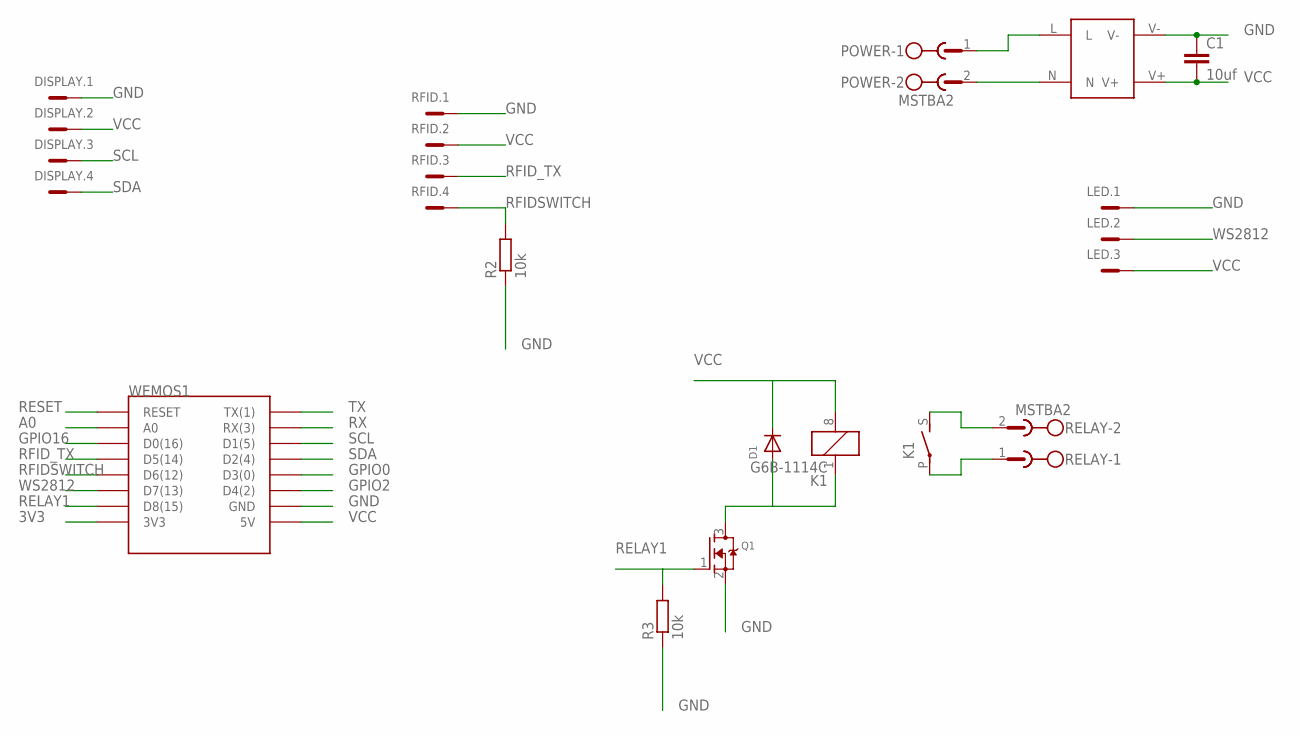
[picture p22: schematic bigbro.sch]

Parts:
C1: 10uf; C0805
D1: DIODESMA; SMADIODE
DISPLAY: MC4
K1: G6B-1114C
LED: MC3
POWER: MSTBA2
Q1: MOSFET-NREFLOW; SOT23
R2, R3: 10k; M0805
RELAY: MSTBA2
RFID: MC4
U$1: HLK-PM03
WEMOS1: WEMOS-D1-MINI

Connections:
3V3: WEMOS1.3V3
A0: WEMOS1.A0
GND: C1.1, DISPLAY.1, LED.1, Q1.2 (S), R2.1, R3.1, RFID.1, U$1.V-, WEMOS1.GND
GPIO0: WEMOS1.D3 (D3(0))
GPIO2: WEMOS1.D4 (D4(2))
GPIO16: WEMOS1.D0 (D0(16))
unnamed: POWER.1, U$1.L
unnamed: POWER.2, U$1.N
unnamed: K1.S, RELAY.2
unnamed: K1.P, RELAY.1
unnamed: D1.A, K1.1, Q1.3 (D)
RELAY1: Q1.1 (G), R3.2, WEMOS1.D8 (D8(15))
RESET: WEMOS1.RESET
RFIDSWITCH: R2.2, RFID.4, WEMOS1.D6 (D6(12))
RFID_TX: RFID.3, WEMOS1.D5 (D5(14))
RX: WEMOS1.RX (RX(3))
SCL: DISPLAY.3, WEMOS1.D1 (D1(5))
SDA: DISPLAY.4, WEMOS1.D2 (D2(4))
TX: WEMOS1.TX (TX(1))
VCC: C1.2, D1.C, DISPLAY.2, K1.8 (2), LED.3, RFID.2, U$1.V+, WEMOS1.5V
WS2812: LED.2, WEMOS1.D7 (D7(13))

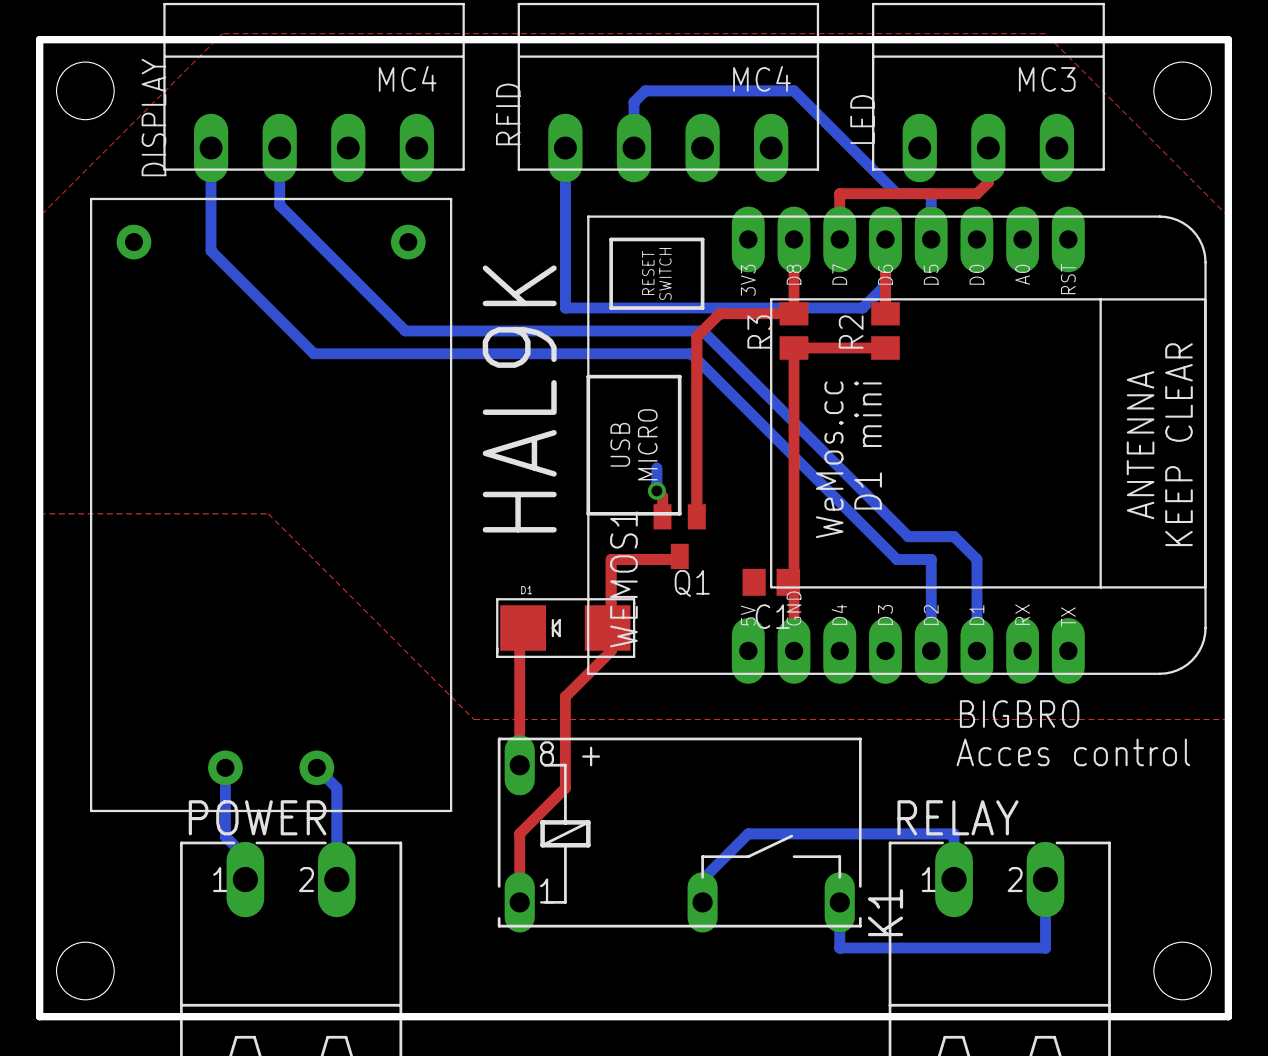
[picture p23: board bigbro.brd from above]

Board: 2 copper layers, 66.0 x 54.3 mm, 13 parts (0 on the bottom side), 13 nets.

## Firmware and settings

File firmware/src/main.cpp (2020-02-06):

#include <controllers/base.h>
#include <controllers/acs.h>
#include <controllers/camera.h>
#include <controllers/printer.h>

/*! @mainpage Documentation for the BigBro firmware
	The BigBro firmware is part of the access system used at Hal9k
	It runs on the access boxes attached to different restricted machines.

	The boxes enable or remove power from the machines, depending on access permissions.

	There are two main types of boxes the users will interact with:
	  - The basic access control box, implemented in ACSController, enables power to machines, 
	  as long as an approved card is present.
	  - The printer access control box, implemented in PrinterController, 
	  enables power to the machines if a valid card is present,
	  or if a print, started with an approved card, is currently in progress.

	  The hardware difference between the two boxes is a higher current capability on the printer box,
	  and a current sensor, as the printer box monitors current consumption of the printers, and therefore
	  passes the entire current for the machine.
	  The basic access control boxes instead use a much smaller relay, to control an external contactor, powering the machine.
*/

/**
 * The active controller instance.
 * BaseController doesn't currently support swapping this at runtime.
 */
BaseController* controller = nullptr;


///Initialization code 
void setup()
{
#if CONTROLLER == 0 && defined(CONTROLLER)
#pragma message "Compiling ACSController"
	controller = new ACSController();
#elif CONTROLLER == 1
#pragma message "Compiling PrinterController"
	controller = new PrinterController();
#elif CONTROLLER == 2
#pragma message "Compiling CameraController"
	controller = new CameraController();

#else // Default controller
#pragma message "Compiling default controller"
	controller = new ACSController();
#endif
}

/**
 * Main control loop
 */
void loop()
{
	controller->update();
    delay(1);
}

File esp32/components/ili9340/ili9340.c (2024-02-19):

#include <stdio.h>
#include <string.h>
#include <inttypes.h>
#include <math.h>

#include "freertos/FreeRTOS.h"
#include "freertos/task.h"

#include <driver/spi_master.h>
#include <driver/gpio.h>
#include "esp_log.h"

#include "ili9340.h"

#define TAG "ILI9340"
#define	_DEBUG_ 0

#if CONFIG_SPI2_HOST
#define TFT_ID SPI2_HOST
#elif CONFIG_SPI3_HOST
#define TFT_ID SPI3_HOST
#else
#define TFT_ID SPI2_HOST // When not to use menuconfig
#define XPT_ID SPI3_HOST // When not to use menuconfig
#endif


//static const int TFT_MOSI = 23;
//static const int TFT_SCLK = 18;

static const int SPI_Command_Mode = 0;
static const int SPI_Data_Mode = 1;
//static const int TFT_Frequency = SPI_MASTER_FREQ_20M;
////static const int TFT_Frequency = SPI_MASTER_FREQ_26M;
static const int TFT_Frequency = SPI_MASTER_FREQ_40M;
////static const int TFT_Frequency = SPI_MASTER_FREQ_80M;

#if CONFIG_XPT2046_ENABLE_SAME_BUS || CONFIG_XPT2046_ENABLE_DIFF_BUS
static const int XPT_Frequency = 1*1000*1000;
//static const int XPT_Frequency = 2*1000*1000;
//static const int XPT_Frequency = 4*1000*1000;

//#define XPT_MISO 19
//#define XPT_CS	4
//#define XPT_IRQ 5
#endif

void spi_master_init(TFT_t * dev, int16_t TFT_MOSI, int16_t TFT_SCLK, int16_t TFT_CS, int16_t GPIO_DC, int16_t GPIO_RESET, int16_t GPIO_BL,
	int16_t XPT_MISO, int16_t XPT_CS, int16_t XPT_IRQ, int16_t XPT_SCLK, int16_t XPT_MOSI)
{
	esp_err_t ret;

	ESP_LOGI(TAG, "TFT_MOSI=%d",TFT_MOSI);
	ESP_LOGI(TAG, "TFT_SCLK=%d",TFT_SCLK);
	ESP_LOGI(TAG, "TFT_CS=%d",TFT_CS);
	gpio_reset_pin( TFT_CS );
	gpio_set_direction( TFT_CS, GPIO_MODE_OUTPUT );
	//gpio_set_level( TFT_CS, 0 );
	gpio_set_level( TFT_CS, 1 );

	ESP_LOGI(TAG, "GPIO_DC=%d",GPIO_DC);
	gpio_reset_pin( GPIO_DC );
	gpio_set_direction( GPIO_DC, GPIO_MODE_OUTPUT );
	gpio_set_level( GPIO_DC, 0 );

	ESP_LOGI(TAG, "GPIO_RESET=%d",GPIO_RESET);
	if ( GPIO_RESET >= 0 ) {
		gpio_reset_pin( GPIO_RESET );
		gpio_set_direction( GPIO_RESET, GPIO_MODE_OUTPUT );
		gpio_set_level( GPIO_RESET, 0 );
		vTaskDelay( pdMS_TO_TICKS( 100 ) );
		gpio_set_level( GPIO_RESET, 1 );
	}

	ESP_LOGI(TAG, "GPIO_BL=%d",GPIO_BL);
	if ( GPIO_BL >= 0 ) {
		gpio_reset_pin( GPIO_BL );
		gpio_set_direction( GPIO_BL, GPIO_MODE_OUTPUT );
		gpio_set_level( GPIO_BL, 0 );
	}

#if CONFIG_XPT2046_ENABLE_SAME_BUS
	spi_bus_config_t tft_buscfg = {
		.sclk_io_num = TFT_SCLK,
		.mosi_io_num = TFT_MOSI,
		.miso_io_num = XPT_MISO,
		.quadwp_io_num = -1,
		.quadhd_io_num = -1
	};
#else
	spi_bus_config_t tft_buscfg = {
		.sclk_io_num = TFT_SCLK,
		.mosi_io_num = TFT_MOSI,
		.miso_io_num = -1,
		.quadwp_io_num = -1,
		.quadhd_io_num = -1
	};
#endif

	ret = spi_bus_initialize( TFT_ID, &tft_buscfg, SPI_DMA_CH_AUTO );
	ESP_LOGI(TAG, "spi_bus_initialize(TFT) ret=%d TFT_ID=%d",ret, TFT_ID);
	assert(ret==ESP_OK);

	spi_device_interface_config_t tft_devcfg={
		.clock_speed_hz = TFT_Frequency,
		.spics_io_num = TFT_CS,
		.queue_size = 7,
		.flags = SPI_DEVICE_NO_DUMMY,
	};

	spi_device_handle_t tft_handle;
	ret = spi_bus_add_device( TFT_ID, &tft_devcfg, &tft_handle);
	ESP_LOGD(TAG, "spi_bus_add_device=%d",ret);
	assert(ret==ESP_OK);
	dev->_dc = GPIO_DC;
	dev->_bl = GPIO_BL;
	dev->_TFT_Handle = tft_handle;

#if CONFIG_XPT2046_ENABLE_DIFF_BUS
	ESP_LOGI(TAG, "XPT_SCLK=%d",XPT_SCLK);
	ESP_LOGI(TAG, "XPT_MOSI=%d",XPT_MOSI);
	ESP_LOGI(TAG, "XPT_MISO=%d",XPT_MISO);
	spi_bus_config_t xpt_buscfg = {
		.sclk_io_num = XPT_SCLK,
		.mosi_io_num = XPT_MOSI,
		.miso_io_num = XPT_MISO,
		.quadwp_io_num = -1,
		.quadhd_io_num = -1
	};

	ret = spi_bus_initialize( XPT_ID, &xpt_buscfg, SPI_DMA_CH_AUTO );
	ESP_LOGI(TAG, "spi_bus_initialize(XPT) ret=%d XPT_ID=%d",ret, XPT_ID);
	assert(ret==ESP_OK);
#endif

#if CONFIG_XPT2046_ENABLE_SAME_BUS || CONFIG_XPT2046_ENABLE_DIFF_BUS
	ESP_LOGI(TAG, "XPT_CS=%d",XPT_CS);
	gpio_reset_pin( XPT_CS );
	gpio_set_direction( XPT_CS, GPIO_MODE_OUTPUT );
	gpio_set_level( XPT_CS, 1 );

	// set the IRQ as a input
	ESP_LOGI(TAG, "XPT_IRQ=%d",XPT_IRQ);
	gpio_config_t io_conf = {};
	io_conf.intr_type = GPIO_INTR_DISABLE;
	io_conf.pin_bit_mask = (1ULL<<XPT_IRQ);
	io_conf.mode = GPIO_MODE_INPUT;
	io_conf.pull_up_en = 1;
	gpio_config(&io_conf);
	//gpio_reset_pin( XPT_IRQ );
	//gpio_set_direction( XPT_IRQ, GPIO_MODE_DEF_INPUT );

	spi_device_interface_config_t xpt_devcfg={
		.clock_speed_hz = XPT_Frequency,
		.spics_io_num = XPT_CS,
		.queue_size = 7,
		.flags = SPI_DEVICE_NO_DUMMY,
	};

	spi_device_handle_t xpt_handle;
#if CONFIG_XPT2046_ENABLE_SAME_BUS
	ret = spi_bus_add_device( TFT_ID, &xpt_devcfg, &xpt_handle);
#else
	ret = spi_bus_add_device( XPT_ID, &xpt_devcfg, &xpt_handle);
#endif
	ESP_LOGD(TAG, "spi_bus_add_device=%d",ret);
	assert(ret==ESP_OK);
	dev->_XPT_Handle = xpt_handle;
	dev->_irq = XPT_IRQ;
	dev->_calibration = true;
#endif
}


bool spi_master_write_byte(spi_device_handle_t SPIHandle, const uint8_t* Data, size_t DataLength)
{
	spi_transaction_t SPITransaction;
	esp_err_t ret;

	if ( DataLength > 0 ) {
		memset( &SPITransaction, 0, sizeof( spi_transaction_t ) );
		SPITransaction.length = DataLength * 8;
		SPITransaction.tx_buffer = Data;
#if 1
		ret = spi_device_transmit( SPIHandle, &SPITransaction );
#endif
#if 0
		ret = spi_device_polling_transmit( SPIHandle, &SPITransaction );
#endif
		assert(ret==ESP_OK); 
	}

	return true;
}

bool spi_master_write_comm_byte(TFT_t * dev, uint8_t cmd)
{
	static uint8_t Byte = 0;
	Byte = cmd;
	gpio_set_level( dev->_dc, SPI_Command_Mode );
	return spi_master_write_byte( dev->_TFT_Handle, &Byte, 1 );
}

bool spi_master_write_comm_word(TFT_t * dev, uint16_t cmd)
{
	static uint8_t Byte[2];
	Byte[0] = (cmd >> 8) & 0xFF;
	Byte[1] = cmd & 0xFF;
	gpio_set_level( dev->_dc, SPI_Command_Mode );
	return spi_master_write_byte( dev->_TFT_Handle, Byte, 2 );
}


bool spi_master_write_data_byte(TFT_t * dev, uint8_t data)
{
	static uint8_t Byte = 0;
	Byte = data;
	gpio_set_level( dev->_dc, SPI_Data_Mode );
	return spi_master_write_byte( dev->_TFT_Handle, &Byte, 1 );
}


bool spi_master_write_data_word(TFT_t * dev, uint16_t data)
{
	static uint8_t Byte[2];
	Byte[0] = (data >> 8) & 0xFF;
	Byte[1] = data & 0xFF;
	gpio_set_level( dev->_dc, SPI_Data_Mode );
	return spi_master_write_byte( dev->_TFT_Handle, Byte, 2);
}

bool spi_master_write_addr(TFT_t * dev, uint16_t addr1, uint16_t addr2)
{
	static uint8_t Byte[4];
	Byte[0] = (addr1 >> 8) & 0xFF;
	Byte[1] = addr1 & 0xFF;
	Byte[2] = (addr2 >> 8) & 0xFF;
	Byte[3] = addr2 & 0xFF;
	gpio_set_level( dev->_dc, SPI_Data_Mode );
	return spi_master_write_byte( dev->_TFT_Handle, Byte, 4);
}

bool spi_master_write_color(TFT_t * dev, uint16_t color, uint16_t size)
{
	static uint8_t Byte[1024];
	int index = 0;
	for(int i=0;i<size;i++) {
		Byte[index++] = (color >> 8) & 0xFF;
		Byte[index++] = color & 0xFF;
	}
	gpio_set_level( dev->_dc, SPI_Data_Mode );
	return spi_master_write_byte( dev->_TFT_Handle, Byte, size*2);
}
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

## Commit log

2018-09-15 firmware is currently weirdly broken
    [cardreader.cpp, main.cpp]
2018-09-15 First encounter of issues
    [acs.cpp, base.cpp, base.h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]
2018-09-15 Further reduced complexity to get no interrupts
2018-09-22 Changed tx pin to unused, as it is
2018-09-22 fixed current init
2018-09-25 Moved to average of p2p current reading
2018-09-30 Added a bit of delay to show error messages on display
    [acs.cpp]
2018-09-30 Removed averaging of current, reduced threshhold to 50mA
2018-10-19 Revert "Shit is broke"
    This reverts commit e61f9288106303296d63b82bd6558d5188ae119d.
    [acs.cpp, base.cpp, base.h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]
2018-10-19 Cleaned up display, fixed inrush-current state change
    [acs.cpp, base.cpp, base.h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]
2018-10-19 Increased cooldown to 9 minutes. Dissabled OTA during prints and cooldown
2018-10-31 Merged Access-System repo, into bigbro
    [1754449_04.stp, G2RL_2A.step, Power monitor - Case.step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]
2018-10-31 Fixed power-monitor PCB, to match real-life fixes
    [Power-handling.sch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]
2019-03-07 Worked on issue 8, pinned ArduinoJson to v5
    [base.cpp, main.cpp]
2019-03-07 Implemented issue 8 fix
    [acs.cpp, base.cpp]
2019-03-09 Fixed potential EEPROM overflow issue
    [eeprom_wrapper.cpp]
2019-03-09 Updated power_monitor pcb to use IRM-02 PSU
    [Power-handling.sch, power_monitor.kicad_pcb, power_monitor.sch]
2019-03-09 Added folder for other PCB design
2019-03-09 Eagle files uploaded
    [bigbro.brd, bigbro.sch]
2019-03-15 added "clear" function Sets buffer to threshhold. So any new readings either screw the average up or down.
2019-03-15 Fixed printer thinking it was printing for the first minute
2019-03-15 Fixed inrush prevention function
    [printer.cpp]
2019-03-15 Finished up new printer code
2019-03-19 Documented Printer and ACS class
2019-10-28 Add debug functions, fix peak-to-peak calculation.
    [currentsens.cpp]
2021-10-11 Added v2 schematic
    [bigbro_box.kicad_pcb, bigbro_box.kicad_sch]
2021-10-11 Added resistive divider to RX0
    [bigbro_box.kicad_sch]
2021-10-17 Moved to SPDT relay, added 24pin FPC for e-ink
    [bigbro_box.kicad_pcb, bigbro_box.kicad_sch, display.kicad_sch]
2021-10-17 Widened isolation slot
    [bigbro_box.kicad_pcb, bigbro_box.kicad_sch, display.kicad_sch]
2023-03-23 Add from zip file.
    [bigbro_box.kicad_pcb, bigbro_box.kicad_sch, display.kicad_sch]
2023-03-30 Remove unneeded pulldown.
    [bigbro_box.kicad_sch]
2023-04-01 Add local libs/footprints. Add GND testpoint.
    [bigbro_box.kicad_sch]
2023-04-01 Change to RDM6300, etc.
    [bigbro_box.kicad_pcb, bigbro_box.kicad_sch, display.kicad_sch]
2023-04-02 New fuse holder, rearrange footprints.
    [bigbro_box.kicad_pcb, bigbro_box.kicad_sch]
2023-04-02 Optimize allocation of gates.
    [bigbro_box.kicad_pcb, bigbro_box.kicad_sch]
2023-04-02 Change current sense to single pin.
    [bigbro_box.kicad_pcb, bigbro_box.kicad_sch]
2023-04-03 Add 3D model for RDM6300 socket.
    [bigbro_box.kicad_pcb]
2023-04-03 Add 3D model for fuse holder.
    [bigbro_box.kicad_pcb]
2023-04-03 Route flip-flop, reduce width to 100 mm.
    [bigbro_box.kicad_pcb, bigbro_box.kicad_sch]
2023-04-03 Finish routing.
    [bigbro_box.kicad_pcb, bigbro_box.kicad_sch]
2023-04-03 Add extension connector.
    [bigbro_box.kicad_pcb, bigbro_box.kicad_sch]
2023-04-03 Fill zones.
    [bigbro_box.kicad_pcb]
2023-04-04 Remove solder mask on high-current traces.
    [bigbro_box.kicad_pcb]
2023-04-04 Clarify connector labels.
    [bigbro_box.kicad_pcb]
2023-05-06 Improve debug connector labels.
    [bigbro_box.kicad_pcb, bigbro_box.kicad_sch]
2023-05-06 Move display backlight from GPIO12 to GPIO14 to fix boot problem.
    [bigbro_box.kicad_pcb, bigbro_box.kicad_sch]
2023-05-06 Add reset and boot switches.
    [bigbro_box.kicad_pcb, bigbro_box.kicad_sch]
2023-05-06 Add ESP32 skeleton code.
2023-05-06 Add voltage divider for RFID.
    [bigbro_box.kicad_pcb, bigbro_box.kicad_sch]
2023-05-06 Increase value of switch LED resistor.
    [bigbro_box.kicad_pcb, bigbro_box.kicad_sch]
2023-05-06 Add command to read switch; initialize switch GPIO.
2023-05-13 Add RFID pin.
2023-05-13 Flip display connector.
    [bigbro_box.kicad_pcb, bigbro_box.kicad_sch]
2023-05-14 Swap S and D on Q3.
    [bigbro_box.kicad_pcb]
2023-05-14 Forgot to save
    [bigbro_box.kicad_pcb, bigbro_box.kicad_sch]
2023-06-01 PoC for coil holder.
    [bigbro_box.kicad_pcb]
2023-06-01 PoC for switch holder.
2023-06-15 Fix Q3 footprint, Q4 resistor values.
    [bigbro_box.kicad_pcb, bigbro_box.kicad_sch]
2023-06-15 Use PWM for display backlight.
2023-06-28 Add case front.
2023-07-04 Increase width of switch opening.
2023-07-04 Add PCB standoffs.
2024-02-05 Tweak insert hole.
2024-02-14 Copy lots of stuff from ACS frontend.
    [bigbro_box.kicad_sch]
2024-02-19 Switch to new display driver.
    [partitions.csv]
2024-02-25 Fix bug where first progress line was lost.
    [display.cpp]
2024-02-25 Fix backlight config.
    [bigbro_box.kicad_sch]
2024-03-24 Add RTS pullup.
    [bigbro_box.kicad_pcb, bigbro_box.kicad_sch]
2024-08-04 Add OTA FWU support.
    [partitions.csv]
2024-09-06 Fix too little room for switch.
2024-09-07 Reduce insert size slightly.
2024-09-15 Add schematic.
    [bigbro_box.kicad_pcb, bigbro_box.kicad_sch]
2024-10-05 Fix bug where screw holes are offset.
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2024-10-18 Strain relief for cable.
2024-10-31 Add C6.
    [bigbro_box.kicad_pcb, bigbro_box.kicad_sch]
2024-11-04 Do OTA check before starting threads.
2024-11-28 Change C3 to 0608.
    [bigbro_box.kicad_pcb, bigbro_box.kicad_sch]
2024-12-29 Initialize ADC channel, adjust messages.
2024-12-29 Add thermal pad.
    [bigbro_box.kicad_pcb]
2024-12-30 KiCad 9.
    [bigbro_box.kicad_pcb, bigbro_box.kicad_sch]
2024-12-30 Use a smaller fuse.
    [bigbro_box.kicad_pcb, bigbro_box.kicad_sch]
2025-02-22 Add extra transistor.
    [bigbro_box.kicad_pcb, bigbro_box.kicad_sch]
2025-02-24 Start adding JLCPCB part numbers.
    [bigbro_box.kicad_pcb, bigbro_box.kicad_sch]
2025-03-04 Improve debug, remove unused struct member, fix deprecations.
    [console.cpp]
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2025-03-21 Update stencil.
    [bigbro_box.kicad_pcb]
2025-04-20 Remove solder mask from relay traces.
    [bigbro_box.kicad_pcb]
2025-04-21 Add resistor divider for current sense input.
    [bigbro_box.kicad_pcb, bigbro_box.kicad_sch]
2025-04-21 Start adding support for current sensor.
2025-05-01 Use zener.
    [bigbro_box.kicad_pcb, bigbro_box.kicad_sch]
2025-06-04 Add current sense task.
2025-06-04 Use interrupt for current sensor.
2025-07-13 Implement current sense mode.
2025-07-14 Holder for WCS1x00 current sensor module.
2025-08-02 Reduce insert hole size.
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2026-05-30 Remove unneeded transistors and resistors.
2026-06-13 Disable OTA FWU if card switch is active.
2026-06-19 Simplify debug circuitry.
    [bigbro_box.kicad_pcb, bigbro_box.kicad_sch]
2026-06-19 Add power LEDs.
    [bigbro_box.kicad_pcb, bigbro_box.kicad_sch]
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
